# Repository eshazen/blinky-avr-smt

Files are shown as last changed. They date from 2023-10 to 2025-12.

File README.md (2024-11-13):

# blinky-avr-smt

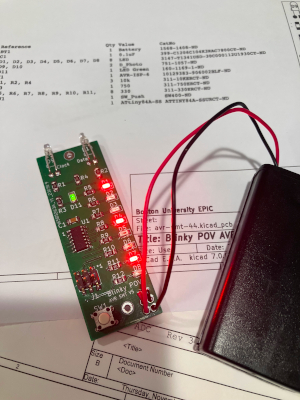
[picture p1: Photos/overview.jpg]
Overview Photo

Blinky

## Blinky POV soldering project

This is a soldering practice kit which displays a message in the air
on LEDs when waved back and forth.  

* Programming: https://ohm.bu.edu/~hazen/BlinkyPovAVR/prog/test_prog.html

## Revisions

Revision 5.1 PCB (fall 2023).  See [PCB Documentation](Hardware/avr-smt-44).

* Improve thermal relief on GND/VCC pads
* Change SMT programming connector to thru-hole
* Add pre-programmed message "EPIC"
* Improve error-checking and display on download code
  (blink all LEDs on checksum error)

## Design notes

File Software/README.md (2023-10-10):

This folder contains software in C to run on the Blinky POV AVR Rev 4 hardware.
The thru-hole version fabricated last in 2014 and a new SMT version fabricated
in 2023 are interchangeable from a software standpoint.

### "test1" is a simple LED test

### "Firmware_V4" is the main blinky firmware.

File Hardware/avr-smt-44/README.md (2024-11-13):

# avr-smt-44

KiCAD design for an SMT version based on ATTiny44/84.
Should be pin/firmware compatible with BlinkyPovAVR4.

## Documentation

* [avr-smt-44.pdf](avr-smt-44.pdf) -- Electrical Schematic
* [avr-smt-44.step](avr-smt-44.step) -- 3D model of assembled board
* [avr-smt-44-Edge_Cuts.pdf](avr-smt-44-Edge_Cuts.pdf) -- Assembly/mechanical drawing
* [avr-smt-44-Edge_Cuts.dxf](avr-smt-44-Edge_Cuts.dxf) -- Assembly/mechanical drawing

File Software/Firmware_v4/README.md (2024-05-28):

# Firmware_v4

This is a C program designed to run on an ATTiny44/84 micro.
It displays a message of up to 127 characters in a 5x8 bitmap on a
column of 8 LEDs.  The character set includes [0-9 A-Z .!&?,].

A new message can be downloaded by pointing the board with two light
sensors at a Javascript applet which converts the text message to a
simplified Intel Hex format and transmits it as a binary code.  Two
squares on the monitor represent "clock" (strobe) and "data".

## Build instructions

On Ubuntu Linux, install the packages `avr-libc`, `gcc-avr` and `avrdude`.
You also need gnu make (suggest to install `build-essential`).

(It is certainly possible to build and download the code on
other OS but I don't have documentation for that.  Google is your friend!)

On Linux:  edit `Makefile` to set `DUDEPORT` appropriately for your programmer.
Two common options are:
* `-c avrispv2 -P usb` for the official ISP V2 or clone
* `-c usbtiny -P usb` for a "USB Tiny" or clone
* `-c avrisp -P /dev/ttyACM0 -b 19200` for Arduino-as-ISP (untested!)

Type `make` to build:

    $ make
    avr-gcc -c -std=c99 -g -Os -mmcu=attiny84 -DF_CPU=1000000 main.c -o main.o
    avr-gcc -Wl,-Map=main.map,--cref -mmcu=attiny84 main.o -o main.elf
    avr-objcopy -j .text -j .data -O ihex main.elf main.hex
    avr-objdump -h -S main.elf > main.lst
    avr-size --common -d main.elf
       text    data     bss     dec     hex filename
       2708      10     171    2889     b49 main.elf

Connect the programming adapter to the 6 pin connector `J1`.
(You may have to install this yourself).

Type `make flash` to program the flash.

## Bugs

Messages longer than 15 characters currently aren't handled correctly
and corrupt the EEPROM.  

For now:  modify the programming code to not allow this

## Details

Each clock pulse causes two data bits to be sampled, the first on the
rising edge and the second on the falling edge.  The most-significant
bit of data is sent first, with 4 clock pulses per byte.

The hex record format is as follows:

`NNHHLLTTDD....CC`

Where:

`NN` is the record length.  0 is ignored, 01-0F are valid

`HH` and `LL` represent the starting address in EEPROM.

`TT` is the record type.  00 represents end-of-message

`CC` is an 8 bit checksum on the data

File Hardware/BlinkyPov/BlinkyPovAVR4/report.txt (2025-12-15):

Info: Backing up file '/home/hazen/work/blinky-avr-smt/Hardware/BlinkyPov/BlinkyPovAVR4/sym-lib-table' to '/home/hazen/work/blinky-avr-smt/Hardware/BlinkyPov/BlinkyPovAVR4/rescue-backup/sym-lib-table-2025-12-15-13-13-25'.
Info: Backing up file '/home/hazen/work/blinky-avr-smt/Hardware/BlinkyPov/BlinkyPovAVR4/tute1.sch' to '/home/hazen/work/blinky-avr-smt/Hardware/BlinkyPov/BlinkyPovAVR4/rescue-backup/tute1-2025-12-15-13-13-25.sch'.
Info: Backing up file '/home/hazen/work/blinky-avr-smt/Hardware/BlinkyPov/BlinkyPovAVR4/tute1.kicad_pro' to '/home/hazen/work/blinky-avr-smt/Hardware/BlinkyPov/BlinkyPovAVR4/rescue-backup/tute1-2025-12-15-13-13-25.kicad_pro'.
Info: Backing up file '/home/hazen/work/blinky-avr-smt/Hardware/BlinkyPov/BlinkyPovAVR4/tute1-cache.lib' to '/home/hazen/work/blinky-avr-smt/Hardware/BlinkyPov/BlinkyPovAVR4/rescue-backup/tute1-cache-2025-12-15-13-13-25.lib'.
Info: Backing up file '/home/hazen/work/blinky-avr-smt/Hardware/BlinkyPov/BlinkyPovAVR4/tute1.cache.lib' to '/home/hazen/work/blinky-avr-smt/Hardware/BlinkyPov/BlinkyPovAVR4/rescue-backup/tute1.cache-2025-12-15-13-13-25.lib'.
Info: Backing up file '/home/hazen/work/blinky-avr-smt/Hardware/BlinkyPov/BlinkyPovAVR4/tute1-rescue.lib' to '/home/hazen/work/blinky-avr-smt/Hardware/BlinkyPov/BlinkyPovAVR4/rescue-backup/tute1-rescue-2025-12-15-13-13-25.lib'.
Info: Backing up file '/home/hazen/work/blinky-avr-smt/Hardware/BlinkyPov/BlinkyPovAVR4/tute1-rescue.dcm' to '/home/hazen/work/blinky-avr-smt/Hardware/BlinkyPov/BlinkyPovAVR4/rescue-backup/tute1-rescue-2025-12-15-13-13-25.dcm'.
Info: Adding library 'tute1-rescue', file '${KIPRJMOD}/tute1-rescue.lib' to project symbol library table.
Info: Created project symbol library table.

Symbol CONN_1 mapped to symbol library 'tute1-rescue'.
Symbol CONN_1 mapped to symbol library 'tute1-rescue'.
Symbol CONN_1 mapped to symbol library 'tute1-rescue'.
Symbol LED mapped to symbol library 'tute1-rescue'.
Symbol LED mapped to symbol library 'tute1-rescue'.
Symbol LED mapped to symbol library 'tute1-rescue'.
Symbol LED mapped to symbol library 'tute1-rescue'.
Symbol LED mapped to symbol library 'tute1-rescue'.
Symbol LED mapped to symbol library 'tute1-rescue'.
Symbol LED mapped to symbol library 'tute1-rescue'.
Symbol LED mapped to symbol library 'tute1-rescue'.
Symbol R mapped to symbol library 'tute1-rescue'.
Symbol LED mapped to symbol library 'tute1-rescue'.
Symbol LED mapped to symbol library 'tute1-rescue'.
Symbol GND mapped to symbol library 'tute1-rescue'.
Symbol R mapped to symbol library 'tute1-rescue'.
Symbol R mapped to symbol library 'tute1-rescue'.
Symbol VCC mapped to symbol library 'tute1-rescue'.
Symbol GND mapped to symbol library 'tute1-rescue'.
Symbol ATTINY44A-P mapped to symbol library 'tute1-rescue'.
Symbol CONN_1 mapped to symbol library 'tute1-rescue'.
Symbol VCC mapped to symbol library 'tute1-rescue'.
Symbol CONN_1 mapped to symbol library 'tute1-rescue'.
Symbol GND mapped to symbol library 'tute1-rescue'.
Symbol CONN_1 mapped to symbol library 'tute1-rescue'.
Symbol C mapped to symbol library 'tute1-rescue'.
Symbol BATTERY mapped to symbol library 'tute1-rescue'.
Symbol GND mapped to symbol library 'tute1-rescue'.
Symbol SW_PUSH mapped to symbol library 'tute1-rescue'.
Info: Symbol library table mapping complete!
Info: Created project symbol library table.

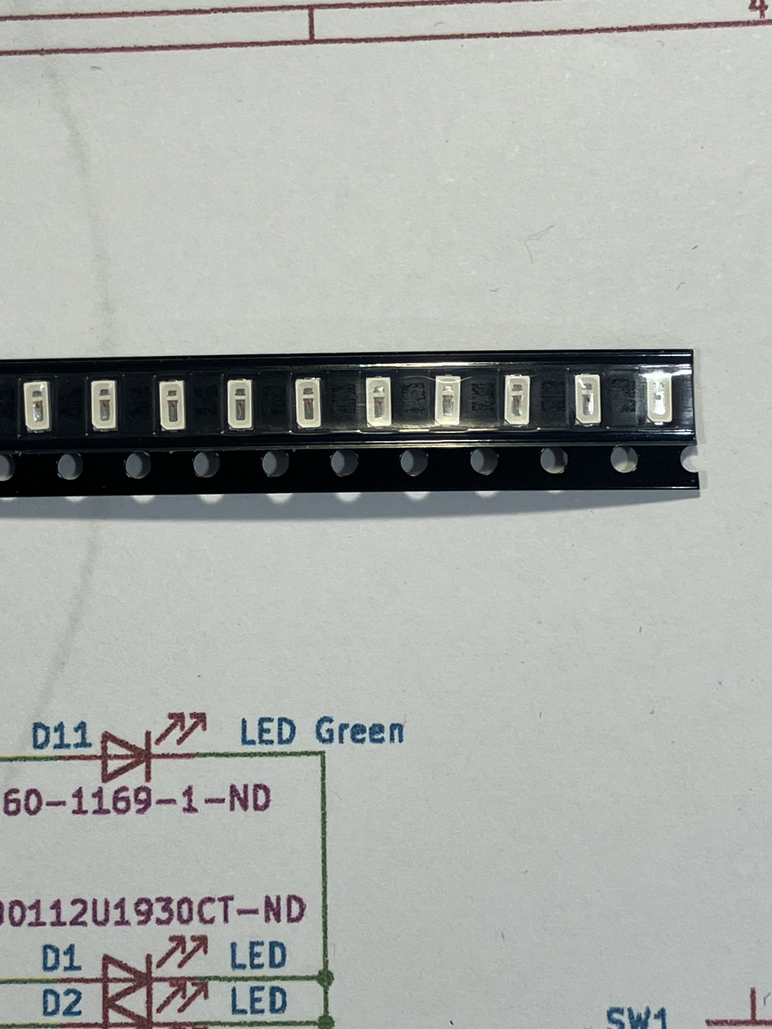
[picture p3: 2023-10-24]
Photos/2023-10-17 13.31.52.jpg

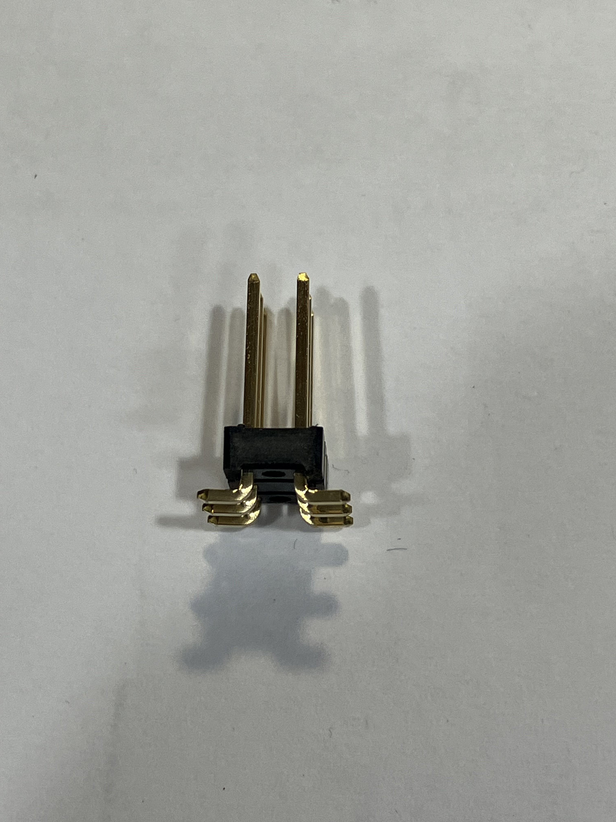
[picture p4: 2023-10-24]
Photos/2023-10-17 13.57.07.jpg

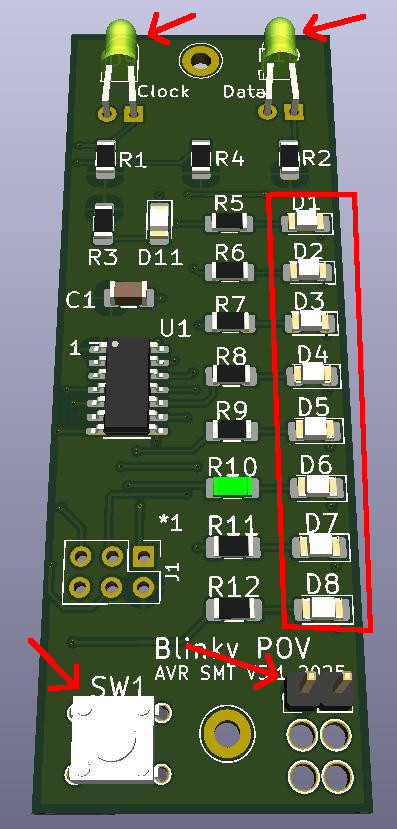
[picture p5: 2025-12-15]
Case2/blinky_3D_front_callouts.jpg

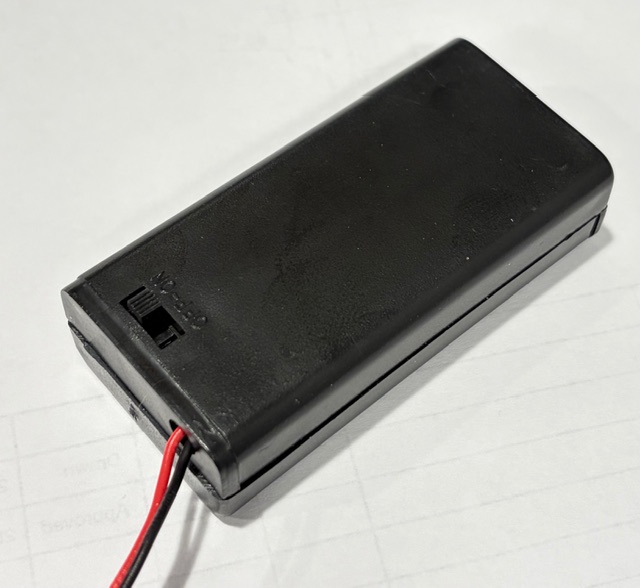
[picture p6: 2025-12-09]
Case2/bat_holder.jpg

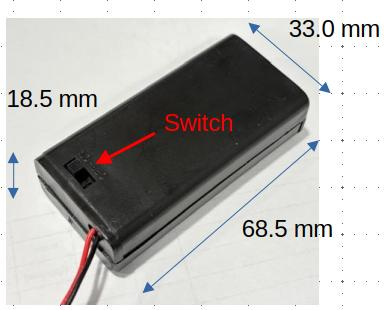
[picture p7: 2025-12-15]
Case2/battery_holder_dims.png

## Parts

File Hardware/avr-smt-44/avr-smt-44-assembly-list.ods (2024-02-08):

# | Reference | Qty | Value | CatNo
1 | BT1 | 1 | Battery | 1568-1408-ND
2 | C1 | 1 | 0.1uF | 399-C1206C104K3RAC7800CT-ND
3 | D1, D2, D3, D4, D5, D6, D7, D8 | 8 | LED | 3147-T1341USD-30C000112U1930CT-ND
4 | D9, D10 | 2 | D_Photo | 751-1057-ND
5 | D11 | 1 | LED Green | 160-1169-1-ND
7 | R1, R2, R4 | 3 | 10k | 311-10KERCT-ND
8 | R3 | 1 | 750 | 311-750ERCT-ND
9 | R5, R6, R7, R8, R9, R10, R11, R12 | 8 | 330 | 311-330ERCT-ND
10 | SW1 | 1 | SW_Push | SW400-ND
11 | U1 | 1 | ATtiny84A-SS | ATTINY84A-SSURCT-ND

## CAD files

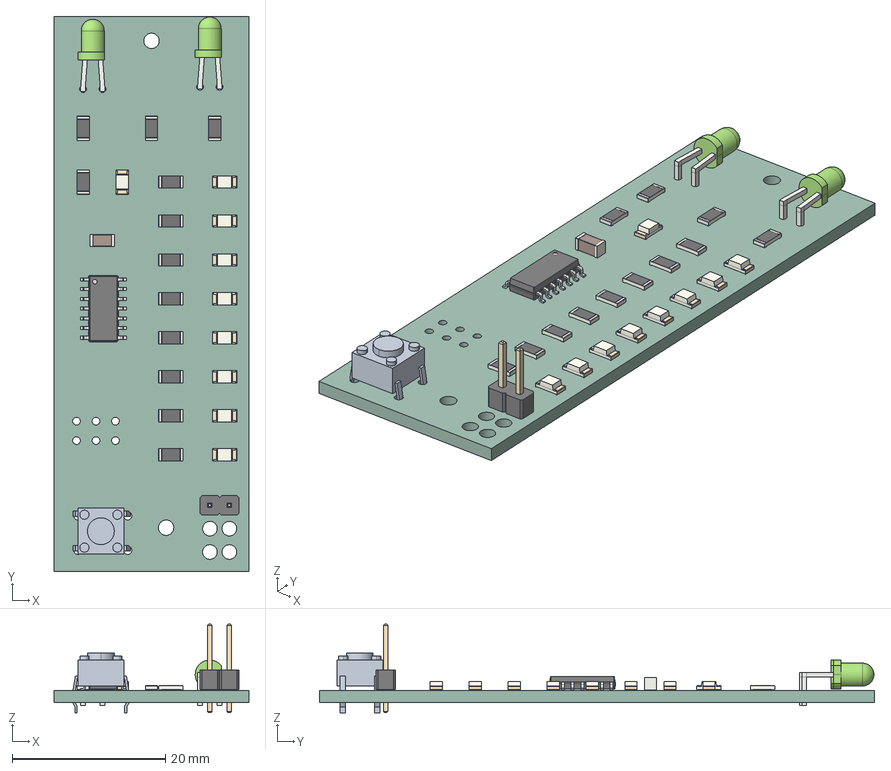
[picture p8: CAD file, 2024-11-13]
Hardware/avr-smt-44/avr-smt-44.step
25.4 x 72.4 x 11.6 mm
C_1206_3216Metric
R_1206_3216Metric x 12
B3F_1000
LED_1206_3216Metric x 9
PinHeader_1x02_P254mm_Vertical
SOIC_14_39x87mm_P127mm
LED_D3.0mm_Horizontal_O3.81mm_Z2.0mm x 2
avr-smt-44_PCB

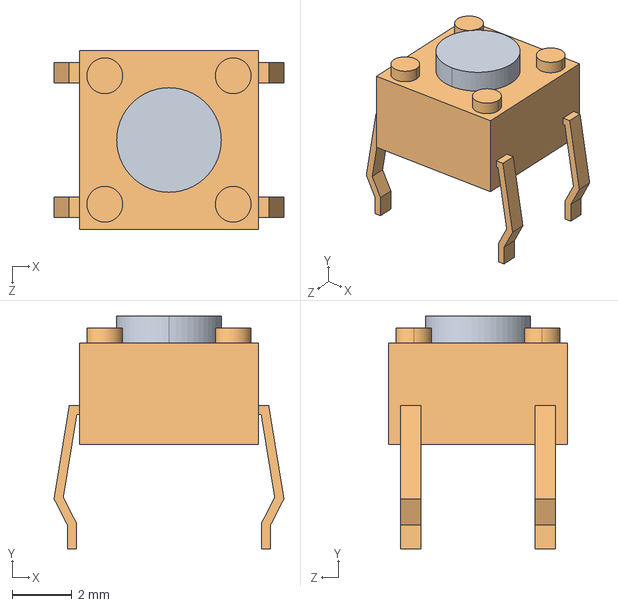
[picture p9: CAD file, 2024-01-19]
Hardware/avr-smt-44/models/B3F-1000.step
7.70 x 7.80 x 6.00 mm
B3F_1000_BUTTON
B3F_1000_BASE

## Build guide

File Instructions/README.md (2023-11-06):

# Instructions for Blinky project

* [Slides](slides.pdf)
* [Kit Page](Kit_Page.pdf) - laminated sheet for parts
* [Assembly Drawing](avr-smt-44-assembly-dwg.pdf)
* [Assembly Notes](Orientation.pdf)
* [Photo](finished.jpg) of completed board

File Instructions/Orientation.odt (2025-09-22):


Blinky POV
Kit

# Assembly Notes

Rev 7/7/25

The assembly drawing is your main reference for placing components on the board. The bill of materials (parts list) includes a “Reference” column which matches the labels on the board (“R1” etc).

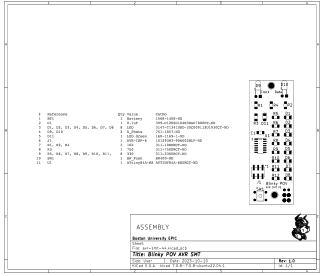
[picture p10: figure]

Docs page:
https://github.com/eshazen/blinky-avr-smt

Resistors and capacitors (R and C) are reversible and can be soldered either way around.

The rest of the parts are not reversible and must be installed the right way around.

Microcontroller (U1)
LEDs (D1-D8 and D11)
Light sensors (D9 and D10)
Battery holder wires

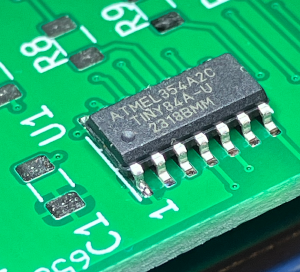
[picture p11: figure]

U1 Orientation

Pin 1 is marked by a dimple in the top of the chip. This should go next to the number “1” on the board.

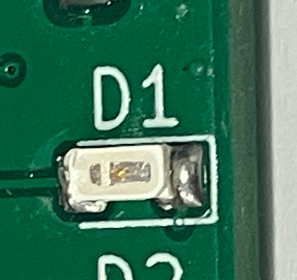
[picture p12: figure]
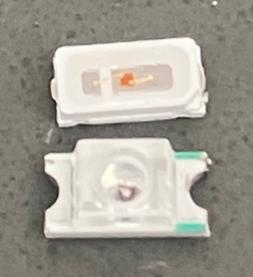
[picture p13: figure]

The LEDs D1-D8 should be mounted as shown.
There are two types of LED… one with a small white bar which goes to the left, the other with green dots which go to the right.

They should be mounted with the white surface with a transparent window facing up.

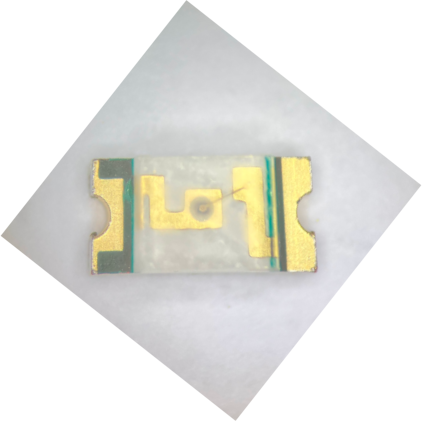
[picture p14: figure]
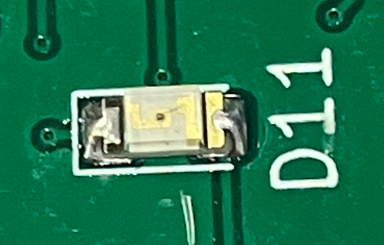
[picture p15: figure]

LED D11 orientation.
You have to look closely
for this one.

LEDs are the most common
type of component to install
incorrectly!

The light sensors (D9, D10) have leads of different lengths.
Bend and install as shown.
Long lead in left hole

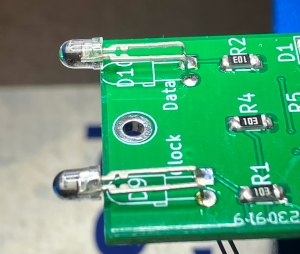
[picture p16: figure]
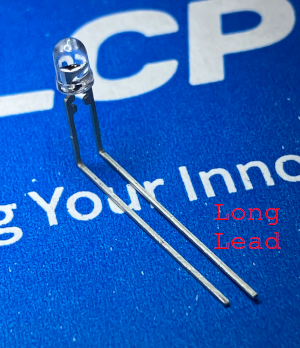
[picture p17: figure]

Trim the extra leads off on the back

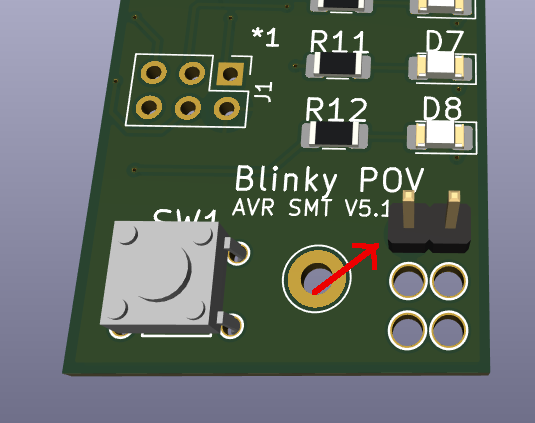
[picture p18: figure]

J1 is not installed

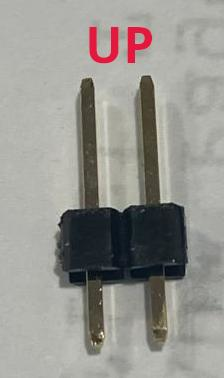
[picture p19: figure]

Install a two-pin header as shown for the battery. The longer pins point UP.

Install the switch SW1 as shown.

Battery connects with Red lead to left

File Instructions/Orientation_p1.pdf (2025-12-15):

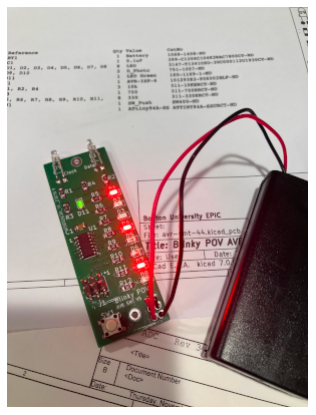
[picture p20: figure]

# Blinky POV Kit

## Assembly Notes

Rev 7/7/25

The assembly drawing is your main reference for placing components on the board. The bill of materials (parts list) includes a “Reference” column which matches the labels on the board
(“R1” etc).
Docs page:


### https://github.com/eshazen/blinky-avr-smt

Resistors and capacitors (R and C) are reversible and can be soldered either way around. The rest of the parts are not reversible and must be installed the right way around. Microcontroller (U1)
LEDs (D1-D8 and D11)
Light sensors (D9 and D10)
Battery holder wires
U1 Orientation
Pin 1 is marked by a dimple in the top of the chip. This should go next to the number “1” on the board.

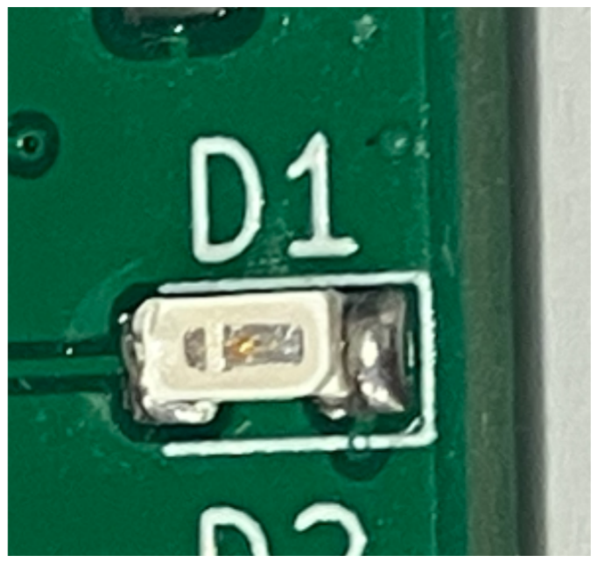
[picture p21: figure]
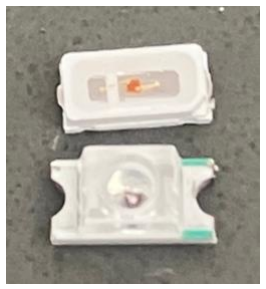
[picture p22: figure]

The LEDs D1-D8 should be mounted as shown. There are two types of LED… one with a small white bar which goes to the left, the other with green dots which go to the right.
They should be mounted with the white surface with a transparent window facing up.

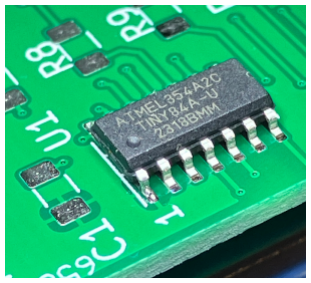
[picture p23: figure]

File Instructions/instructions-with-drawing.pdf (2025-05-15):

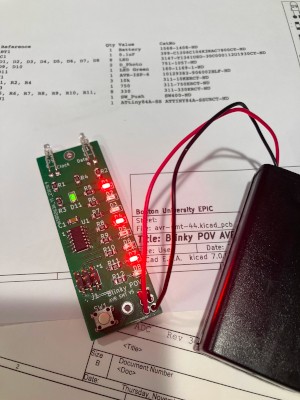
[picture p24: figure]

### Blinky POV

### Kit

Assembly Notes

Rev 5/23/24

The assembly drawing is your main reference for placing components on the board. The bill of materials (parts list) includes a “Reference” column which matches the labels on the board
(“R1” etc).
Docs page:

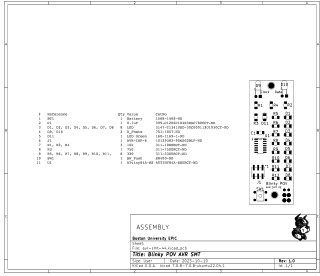
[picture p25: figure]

https://github.com/eshazen/blinky-avr-smt

Resistors and capacitors (R and C) are reversible and can be soldered either way around. The rest of the parts are not reversible and must be installed the right way around. Microcontroller (U1)
LEDs (D1-D8 and D11)
Light sensors (D9 and D10)
Battery holder wires
U1 Orientation
Pin 1 is marked by a dimple in the top of the chip. This should go next to the number “1” on the board.

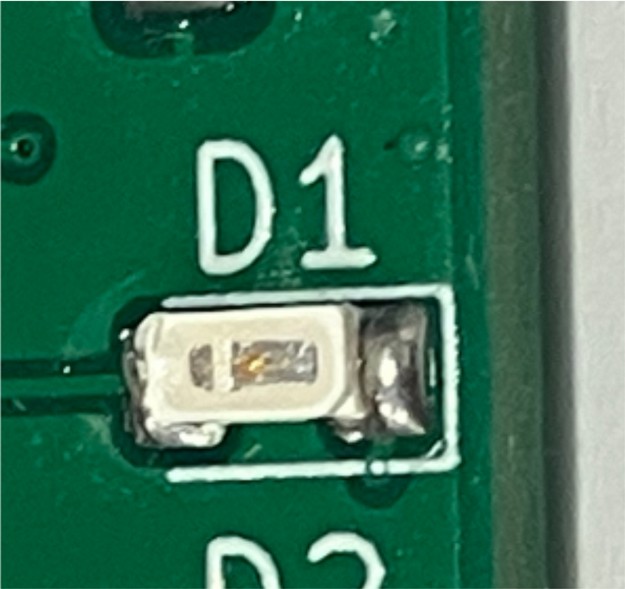
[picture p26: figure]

The LEDs D1-D8 should be mounted as shown, with the wider opening towards the board edge.
They should be mounted with the white surface with a transparent window facing up.

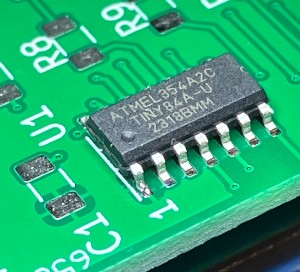
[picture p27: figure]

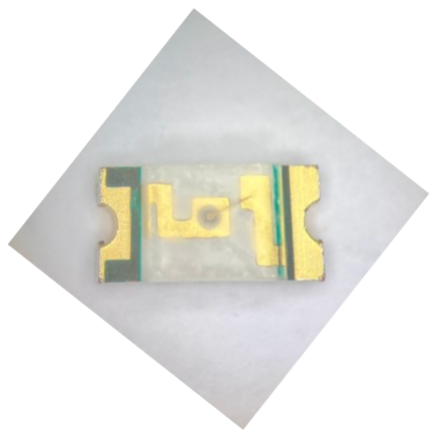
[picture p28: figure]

LED D11 orientation.
You have to look closely
for this one.

LEDs are the most common
type of component to install incorrectly!

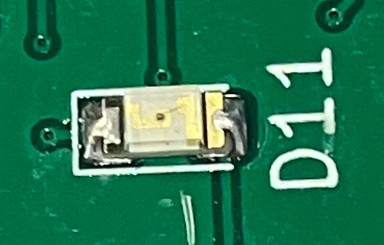
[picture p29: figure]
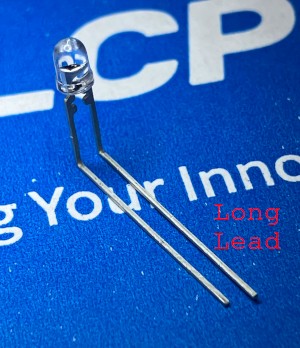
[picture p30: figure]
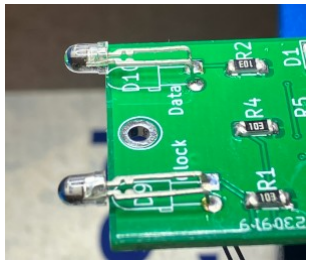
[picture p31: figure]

The light sensors (D9, D10) have leads of different lengths.
Bend and install as shown.
Long lead in left hole
Trim the extra leads off on the back

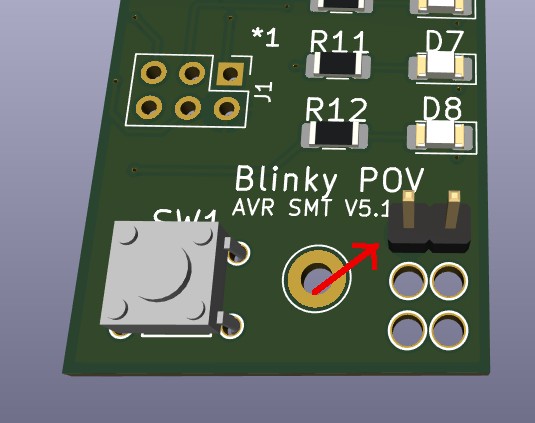
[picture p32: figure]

J1 is not installed
Install a two-pin header
as shown for the battery.
Install the switch SW1
as shown.
Battery connects with
Red lead to left

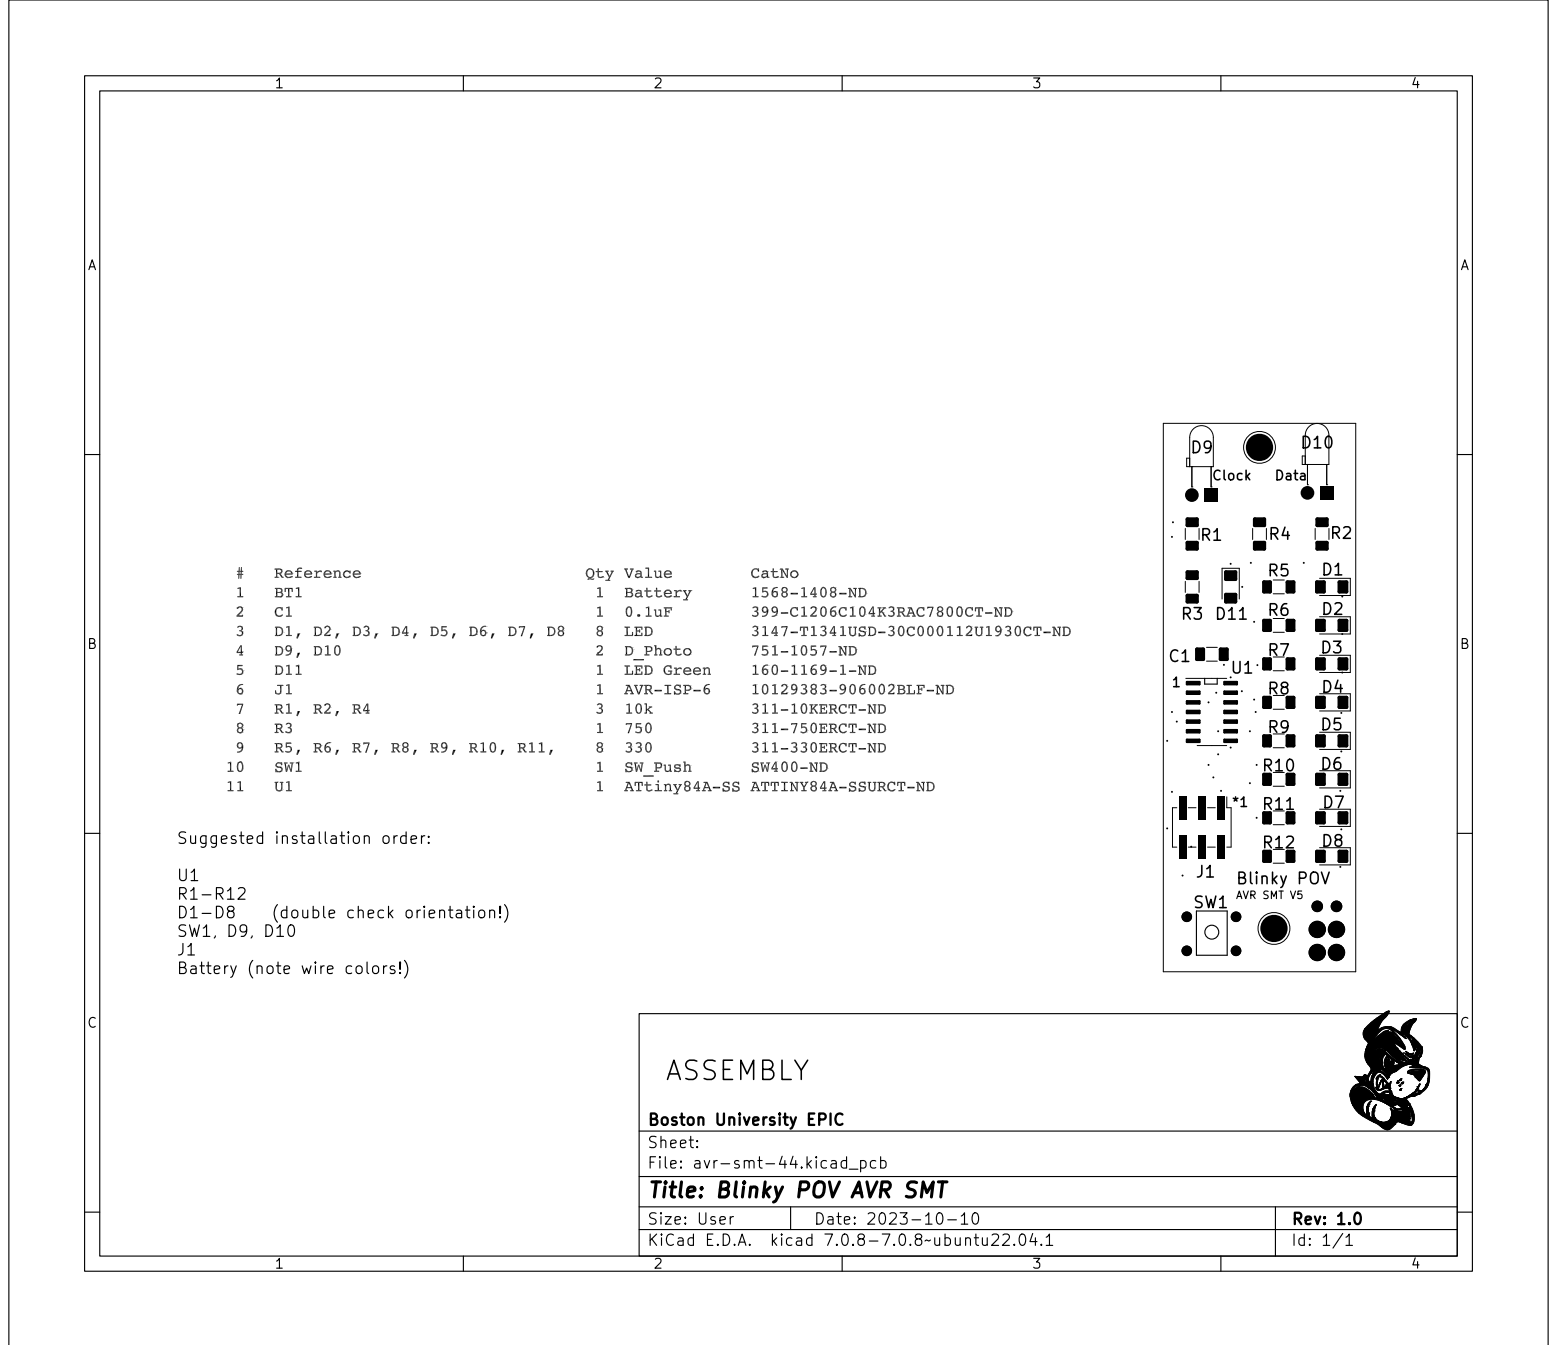
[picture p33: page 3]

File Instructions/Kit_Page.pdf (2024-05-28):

Blinky POV AVR SMT Kit V5.1

C1 – 0.1uF

D1-D8 – red LED

D9, D10 - photodiode

D11 – green LED

### 2 pin header

(battery, next to “V5.1”)

R1,R2,R4 – 10k resistor
R3 – 750 ohm resistor

R5..R12 – 330 ohm resistor

SW1 - pushbutton

U1 – ATTiny84 microcontroller

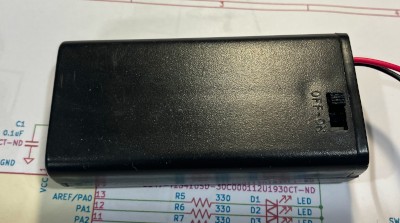
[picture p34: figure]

BT1 – Battery Case

Rev 5/23/24

Suggest to install in order...

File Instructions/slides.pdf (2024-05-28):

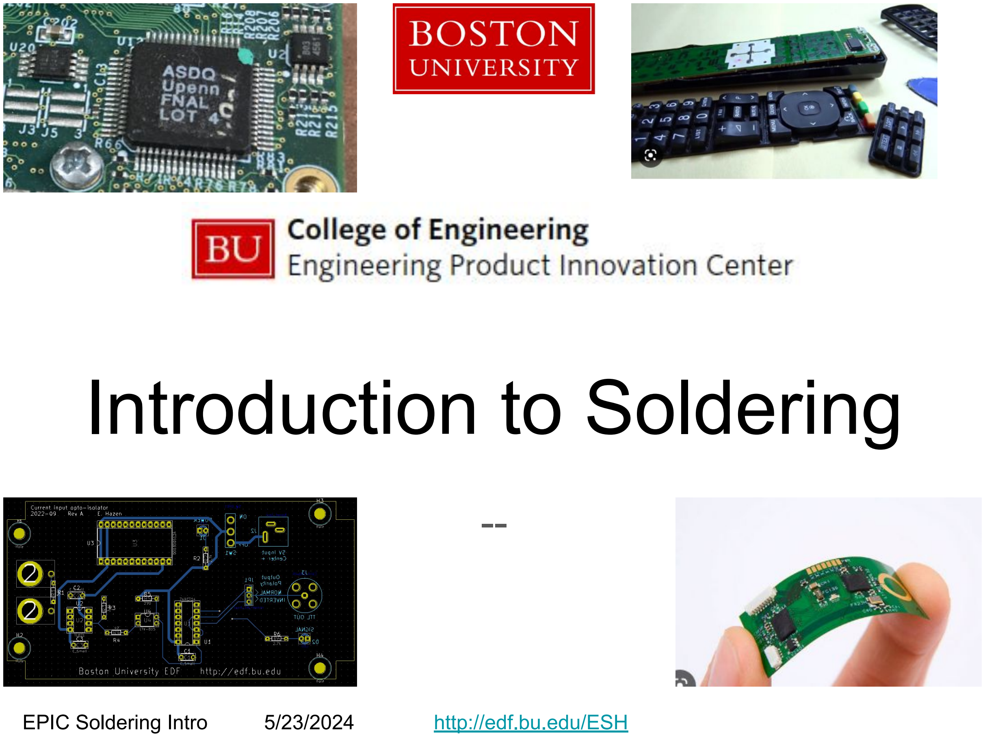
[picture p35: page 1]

EPIC Soldering Intro | 5/23/2024 | http://edf.bu.edu/ESH

# Introduction to Soldering

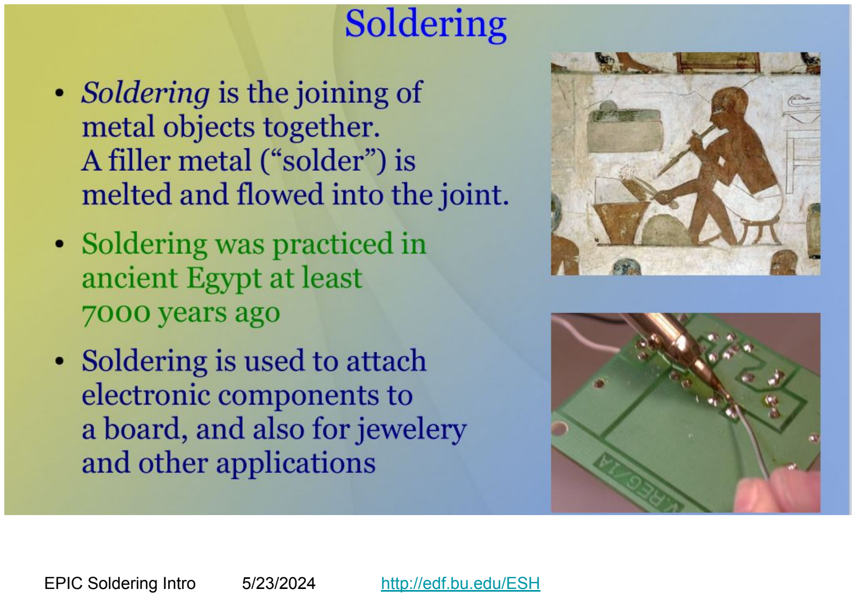
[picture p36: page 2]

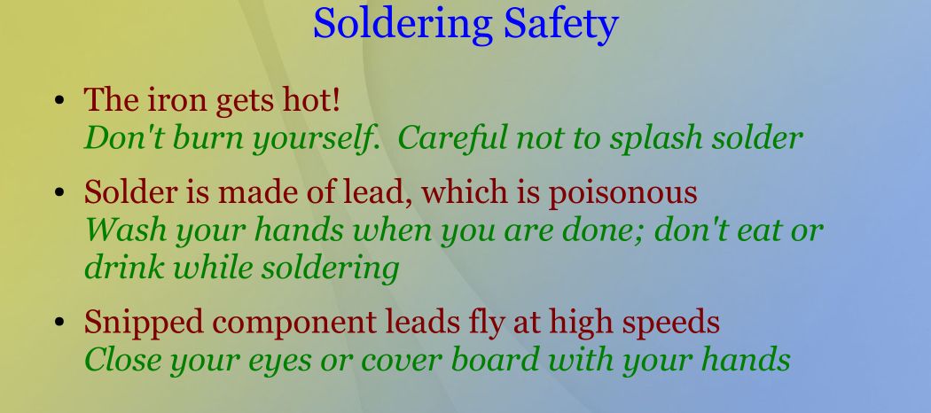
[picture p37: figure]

Thru-hole (THT) | vs | Surface Mount (SMT)

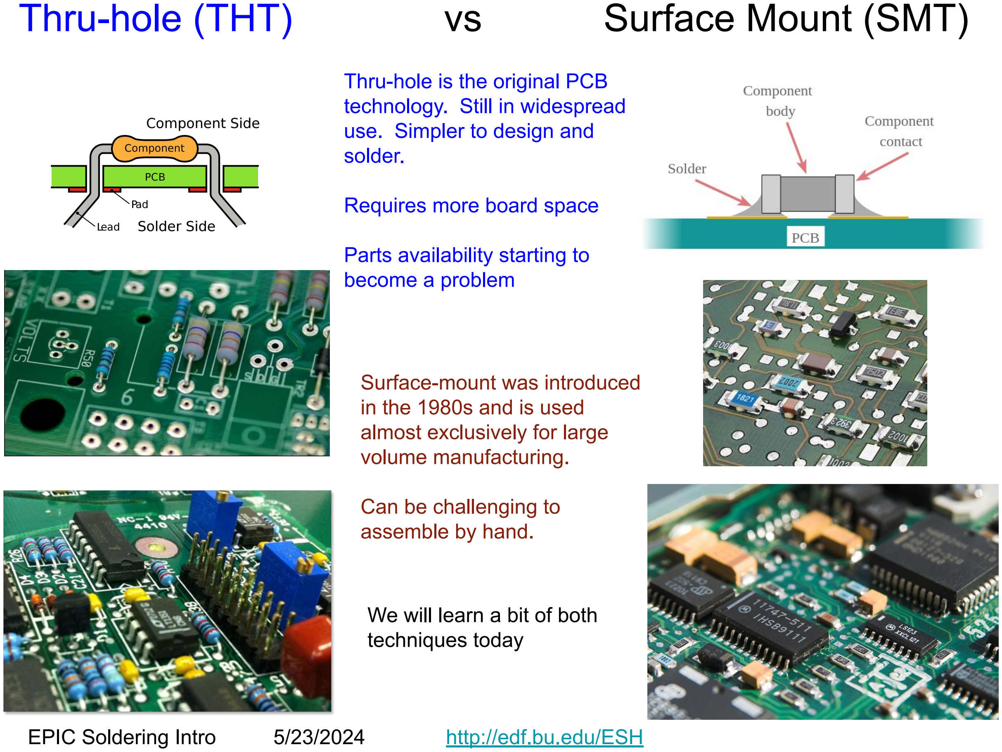
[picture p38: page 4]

Thru-hole is the original PCB technology. Still in widespread use. Simpler to design and solder.

Requires more board space

Parts availability starting to become a problem

Surface-mount was introduced in the 1980s and is used
almost exclusively for large volume manufacturing.

Can be challenging to
assemble by hand.

We will learn a bit of both techniques today

# Today’s Project!

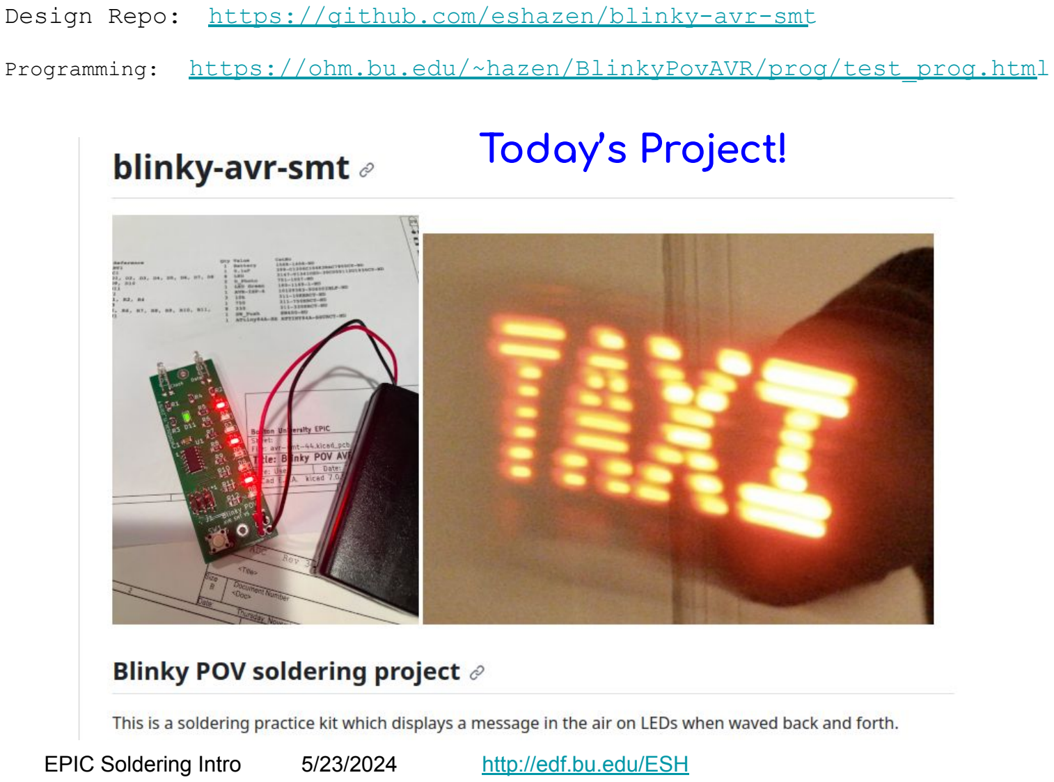
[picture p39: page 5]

Programming: | https://ohm.bu.edu/~hazen/BlinkyPovAVR/prog/test_prog.html
Design Repo: | https://github.com/eshazen/blinky-avr-smt

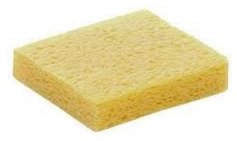
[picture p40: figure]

# Soldering - Tips and Tricks

## - Tin-Lead (PbSn) solder works best

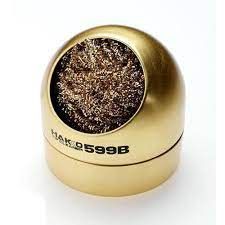
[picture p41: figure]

## - Get the sponge wet before starting - Set the iron temperature to ~ 750 F - Wipe the tip on the sponge and “tin” with new solder before each operation (if the tip gets dirty, clean on brass sponge) - If you aren’t using the iron, turn it off

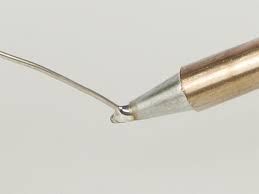
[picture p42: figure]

## The tip should look like this before you start soldering anything!

# Soldering two-terminal SMDs (resistors, capacitors)

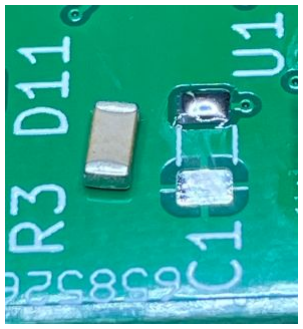
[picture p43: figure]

## - Apply solder to one pad (“tinning”) clean and tin soldering iron touch iron to pad count to 3 slowly feed in some solder keep iron on pad count to 3 slowly remove tip

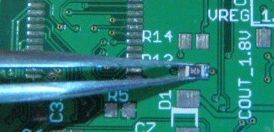
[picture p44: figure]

## - Heat solder until it melts Use tweezers to slide component into place

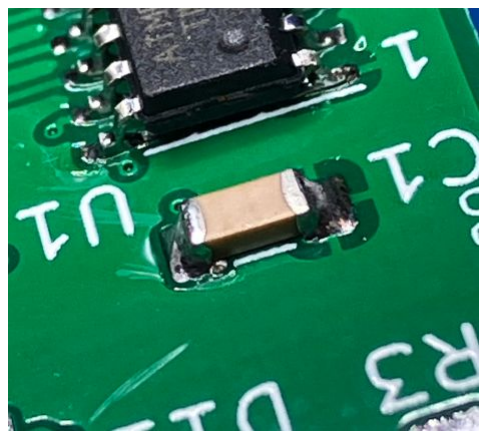
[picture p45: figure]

## - Heat the other end count to 3 apply some solder keep iron on joint count to 3

## SMD = Surface Mount Device

# Soldering Thru-Hole Devices

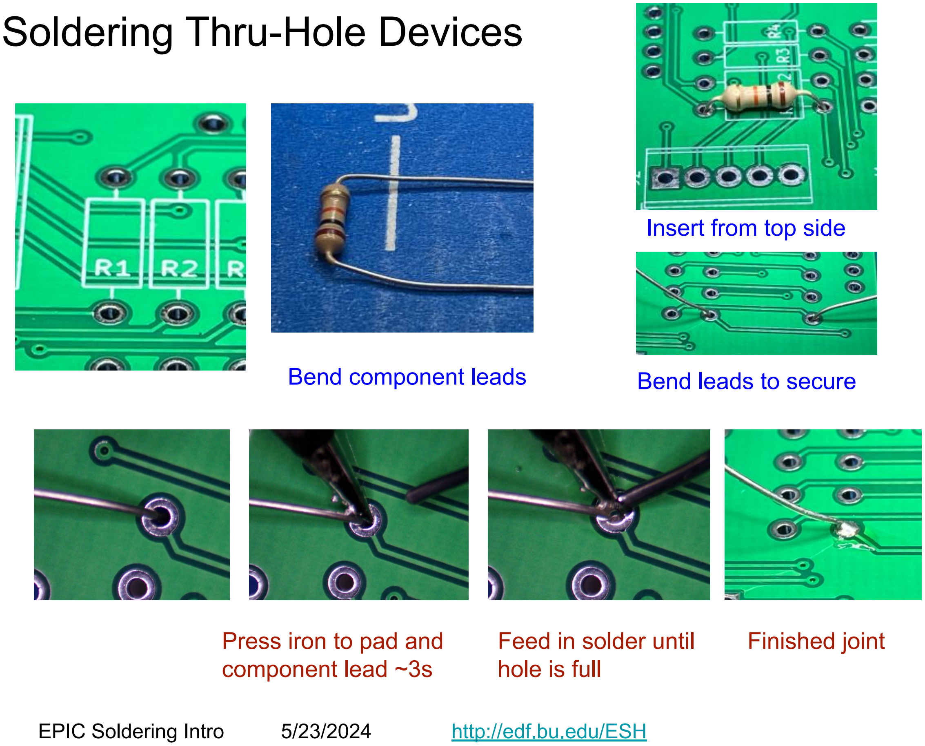
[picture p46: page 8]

Bend component leads

Insert from top side

Bend leads to secure

Press iron to pad and
component lead ~3s

Feed in solder until
hole is full

Finished joint

# Soldering - suggest to install in order on parts kit

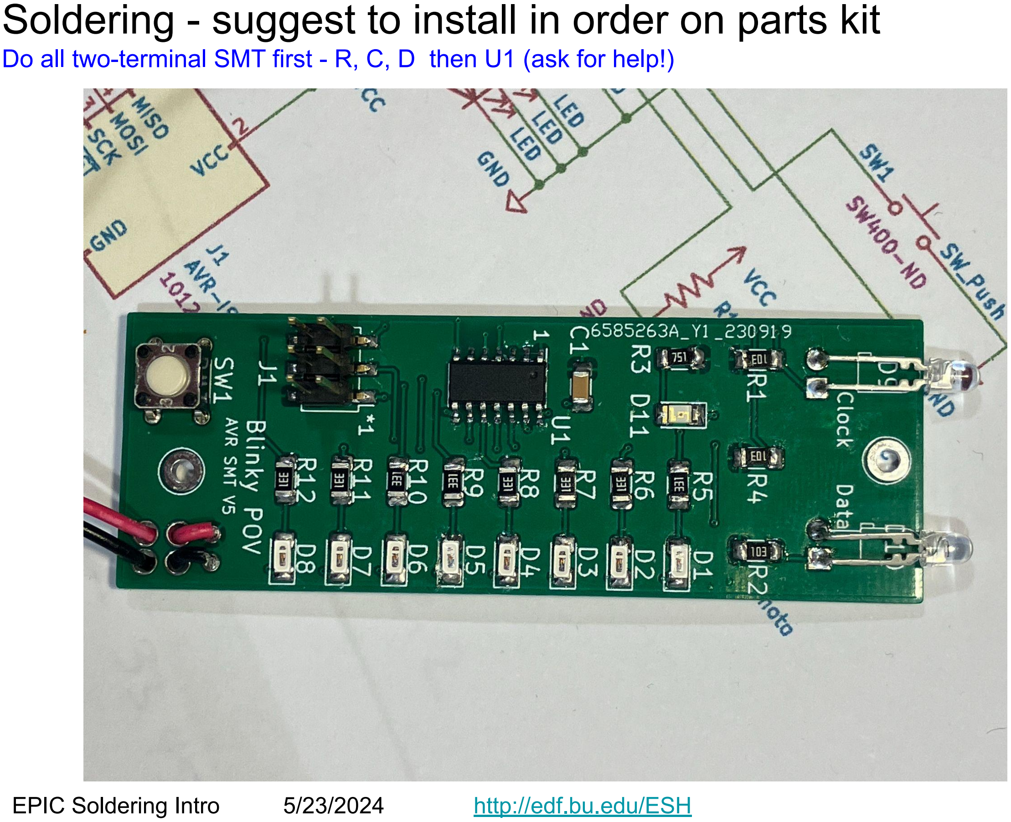
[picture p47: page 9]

Do all two-terminal SMT first - R, C, D then U1 (ask for help!)

# When you’re done…

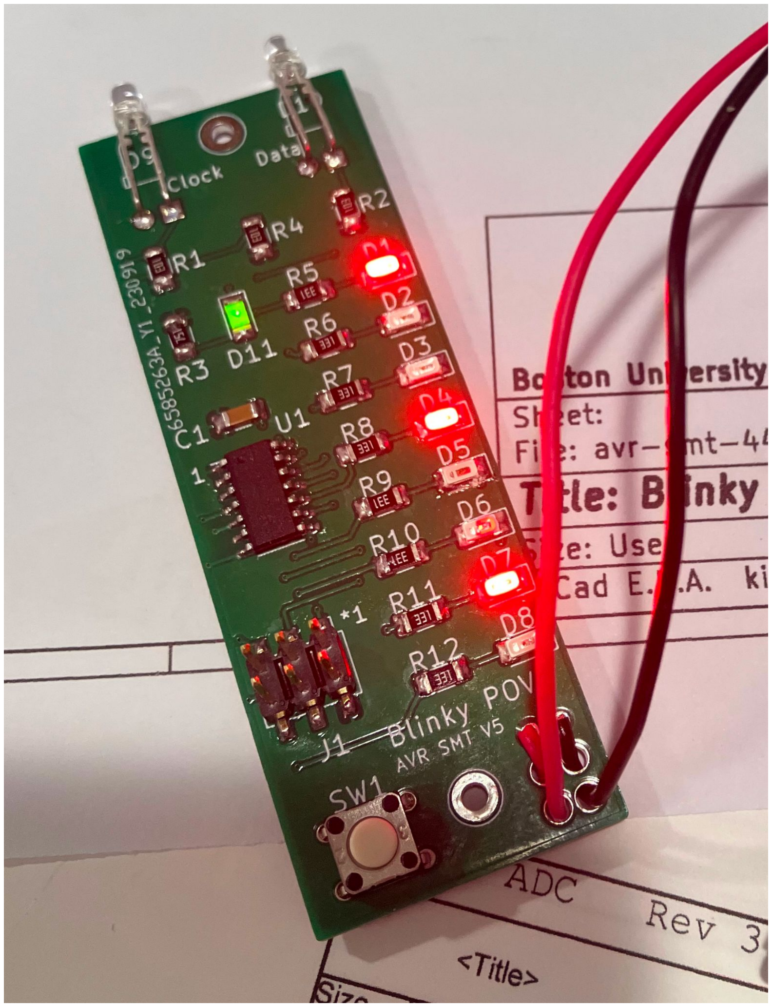
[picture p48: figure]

## After you finish soldering, get your work inspected

(This will prevent damage due to incorrectly installed parts)

## Connect battery with red wire to left

## Hold SW1 (button down) when powering up first

time to reset the message.

All LEDs should flash.

To program a new message into your board,

## visit this site:

https://ohm.bu.edu/~hazen/BlinkyPovAVR/prog/test_prog.html

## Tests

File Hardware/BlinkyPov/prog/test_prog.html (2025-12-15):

# Blinky POV Programming

Message:
Available characters: 0-9, A-Z, !, ?, &, \',\', and \'.\'.



Progress: Canceled

| | Delay (ms):

Data

Clock

Programming Instructions: Enter your message in the "Message" box.

- Hold board up to monitor as shown, with the LEDs up. The light sensors must point at the two squares marked "Clock" and "Data".
- Press the white button on the board. The top LED (D8) should come on and then go off.
- Click the "Go" button above. The squares will flash, and the top LED on your board should flash as the message is downloaded.

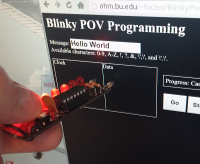
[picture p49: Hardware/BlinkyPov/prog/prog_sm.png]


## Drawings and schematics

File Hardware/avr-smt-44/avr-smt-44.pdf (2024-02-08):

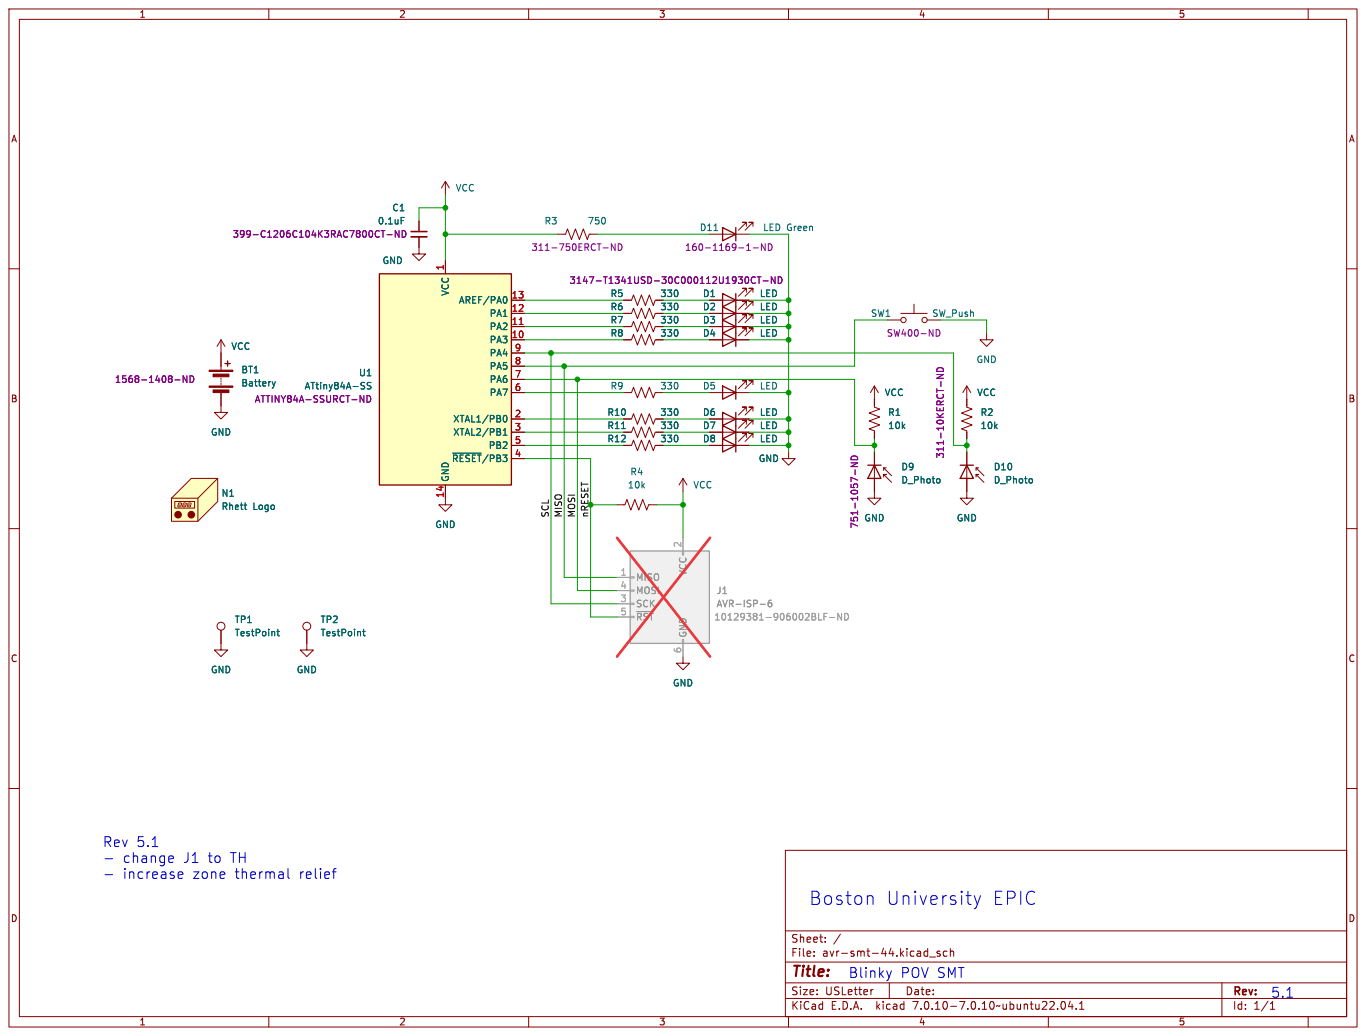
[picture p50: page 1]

1 PA3 10 PA2 11 PA1 12 AREF/PA0 13 GND 14 XTAL1/PB0 2 XTAL2/PB1 3 ~{RESET}/PB34 PB2 5 PA7 6 PA6 7 PA5 8 PA4 9 U1 ATtiny84A-SS

2 SCK 3 MOSI 4 ~{RST} 5 GND

Rev 5.1
- change J1 to TH
- increase zone thermal relief

Id: 1/1 Title: File: avr-smt-44.kicad_sch Sheet: /

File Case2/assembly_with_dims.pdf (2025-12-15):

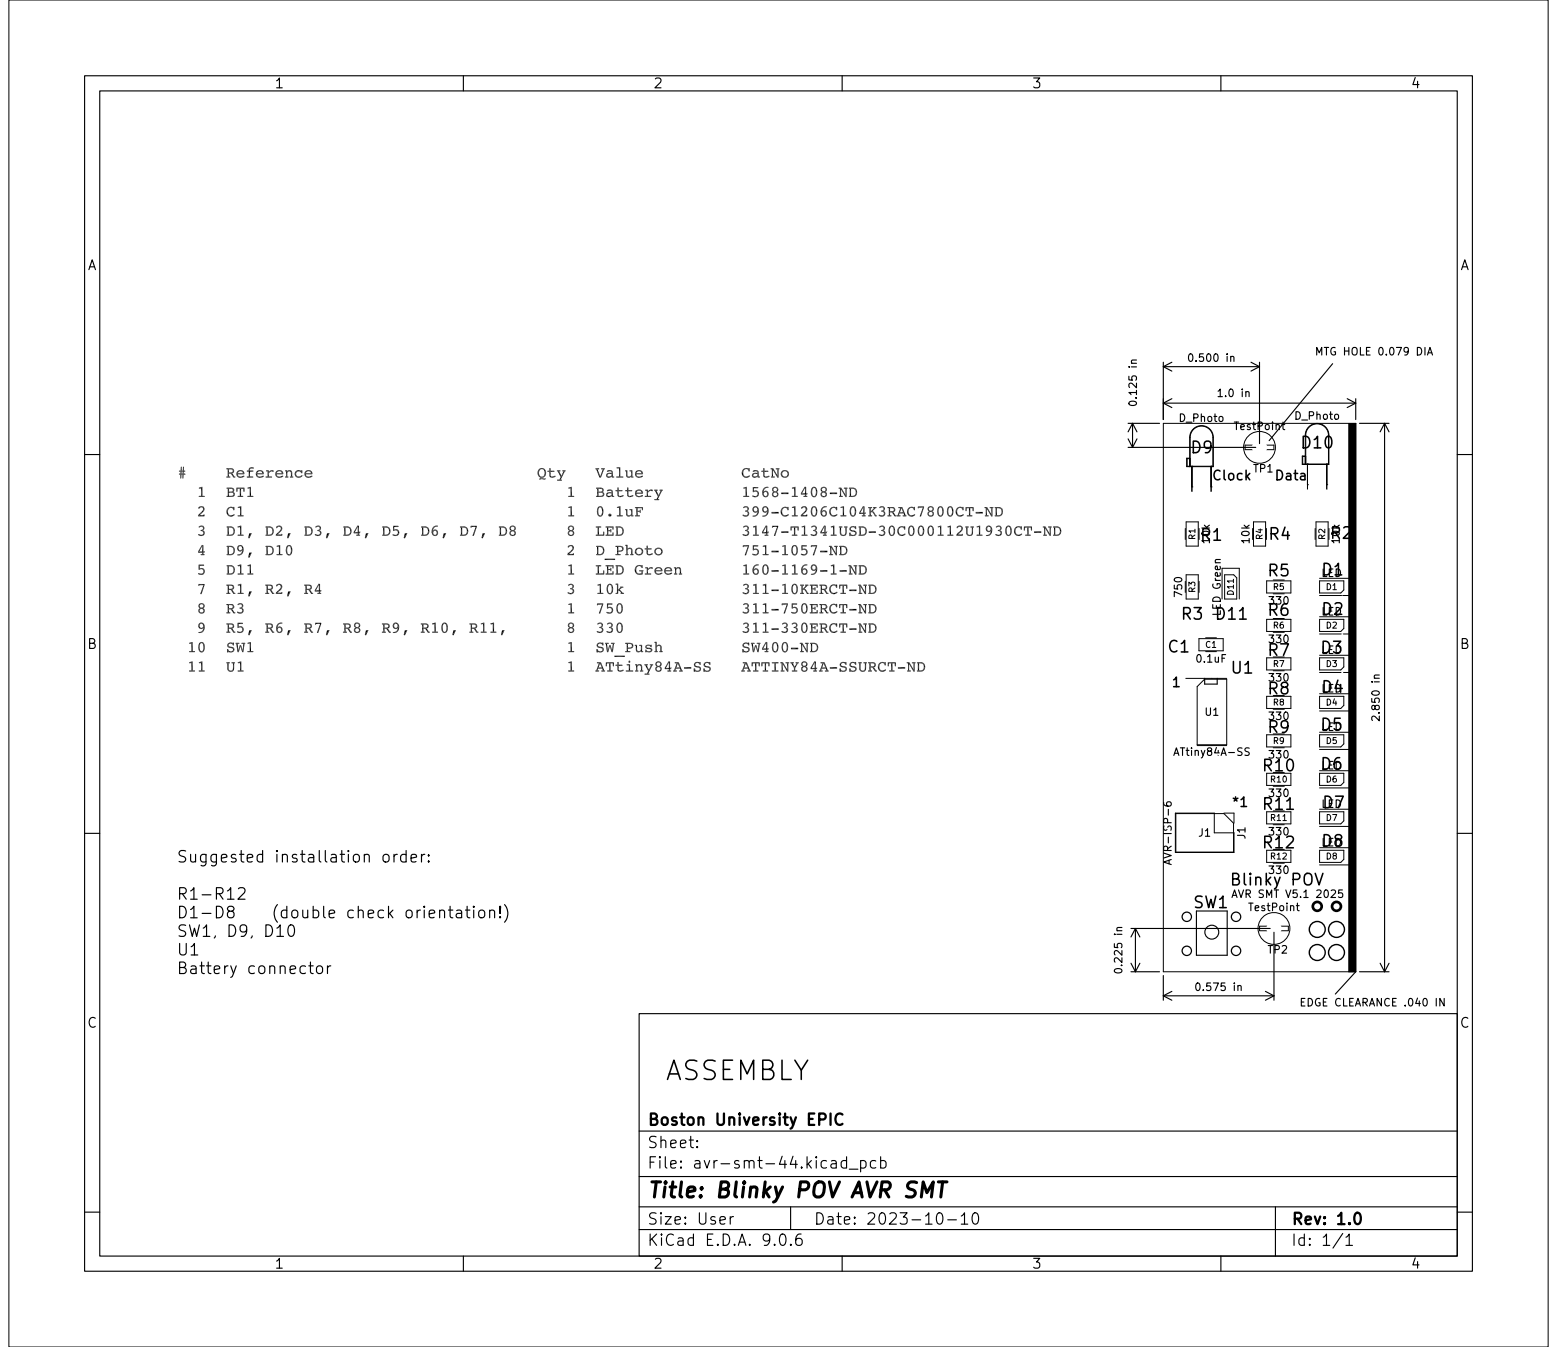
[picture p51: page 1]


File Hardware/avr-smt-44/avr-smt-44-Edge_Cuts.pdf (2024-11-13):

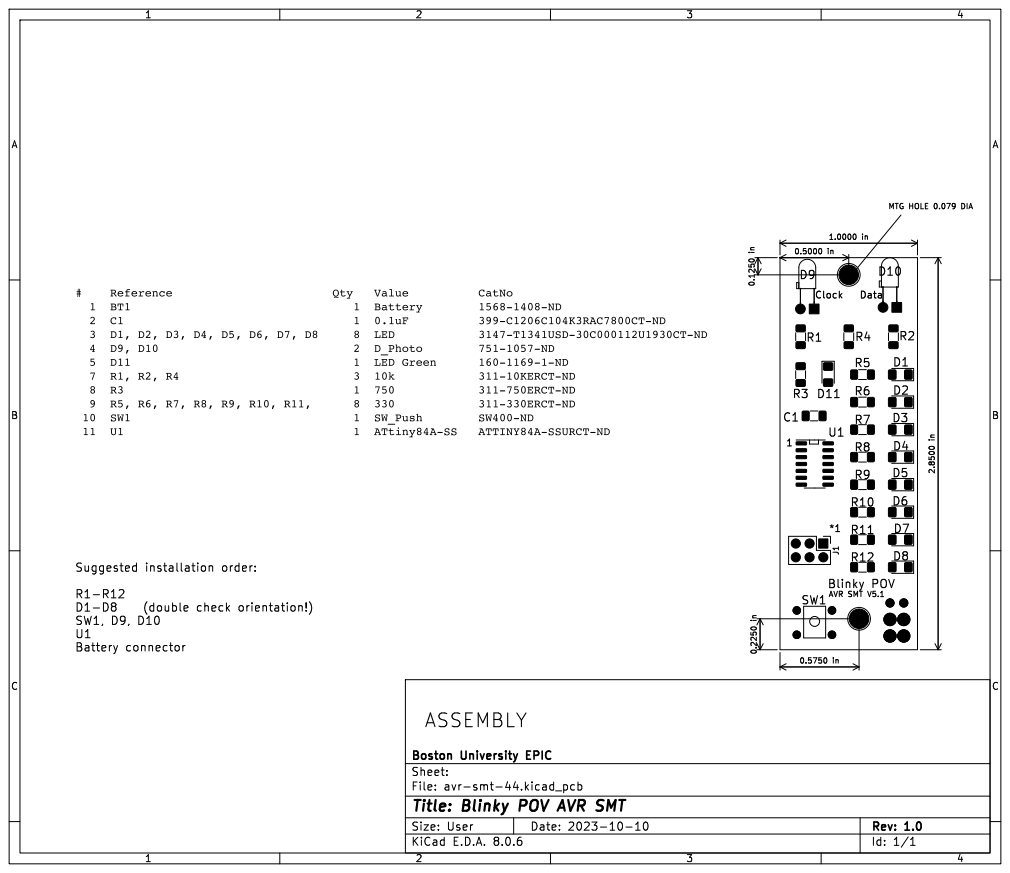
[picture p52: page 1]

Id: 1/1 Title: Blinky POV AVR SMT

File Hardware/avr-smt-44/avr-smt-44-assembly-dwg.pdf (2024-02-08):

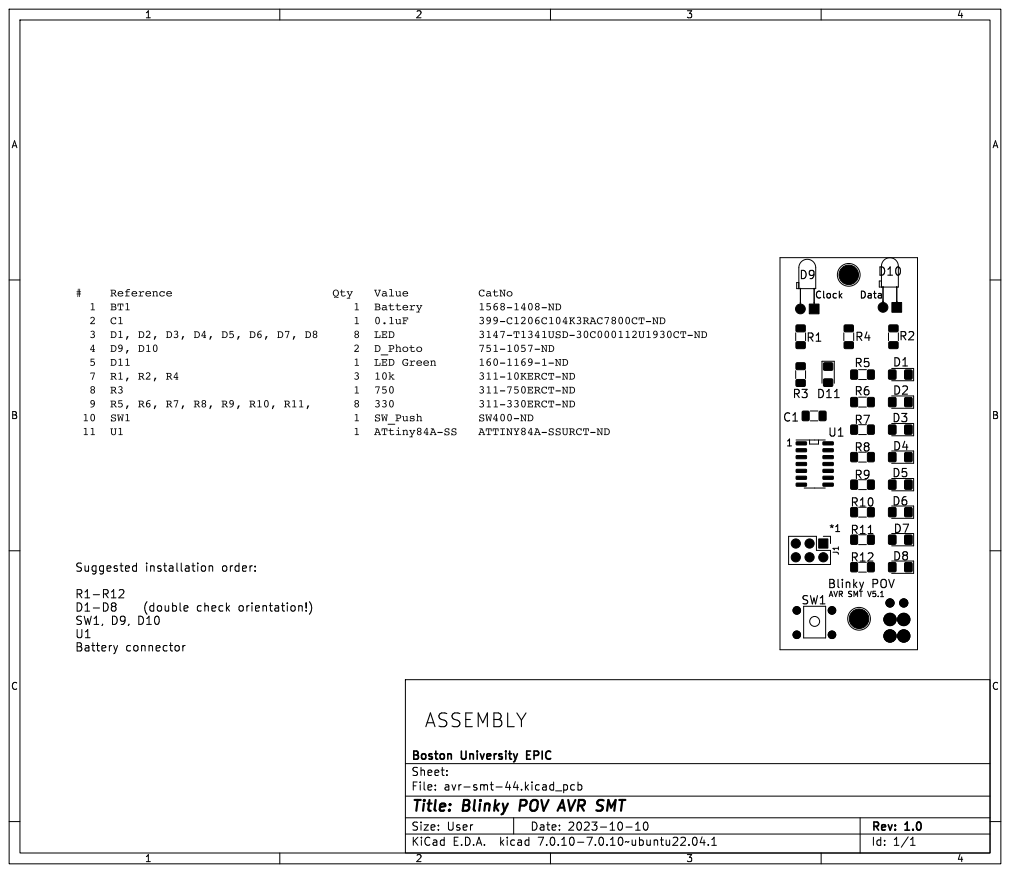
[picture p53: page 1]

Id: 1/1 Title: Blinky POV AVR SMT

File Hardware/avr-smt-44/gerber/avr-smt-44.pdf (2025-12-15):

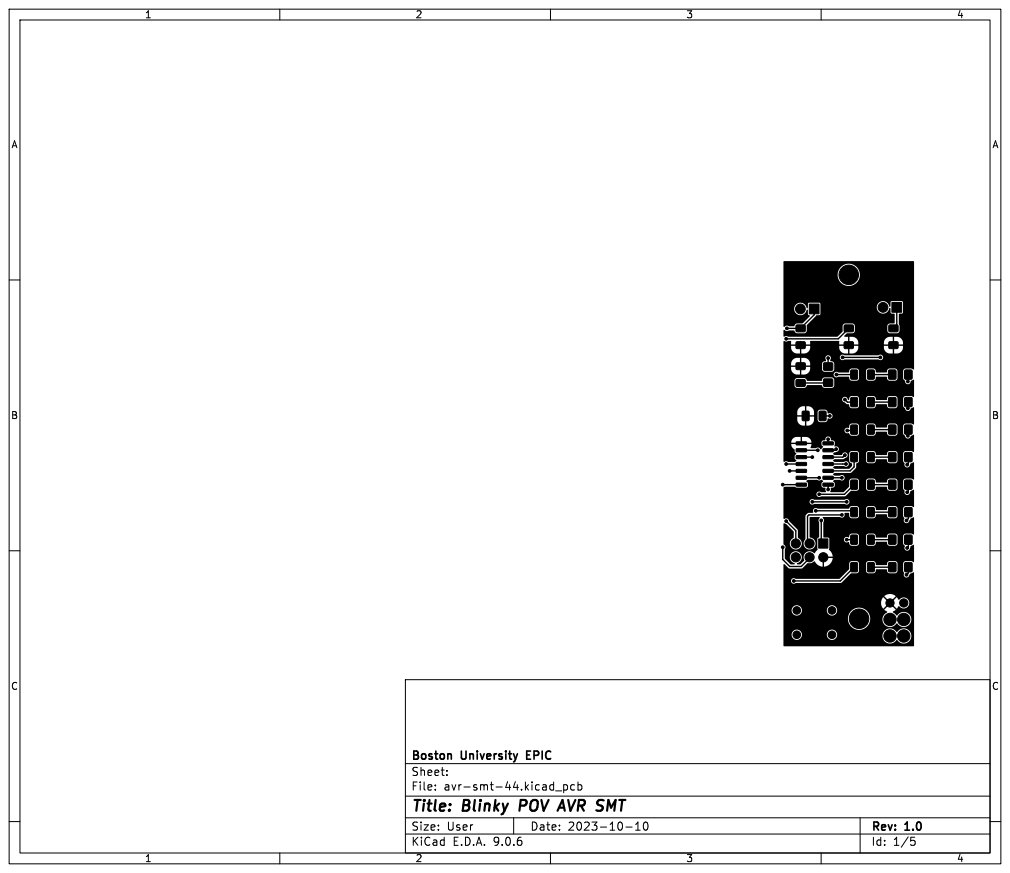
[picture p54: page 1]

Id: 1/5 Title: Blinky POV AVR SMT

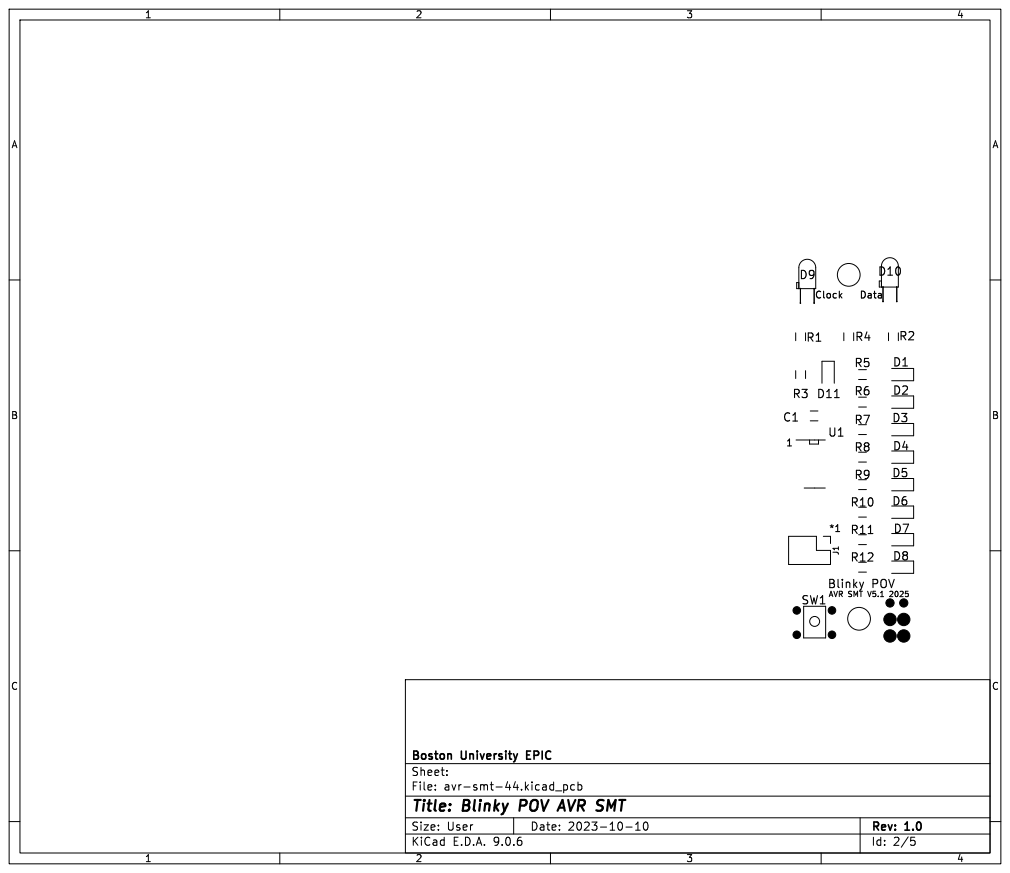
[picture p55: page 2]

Id: 2/5 Title: Blinky POV AVR SMT

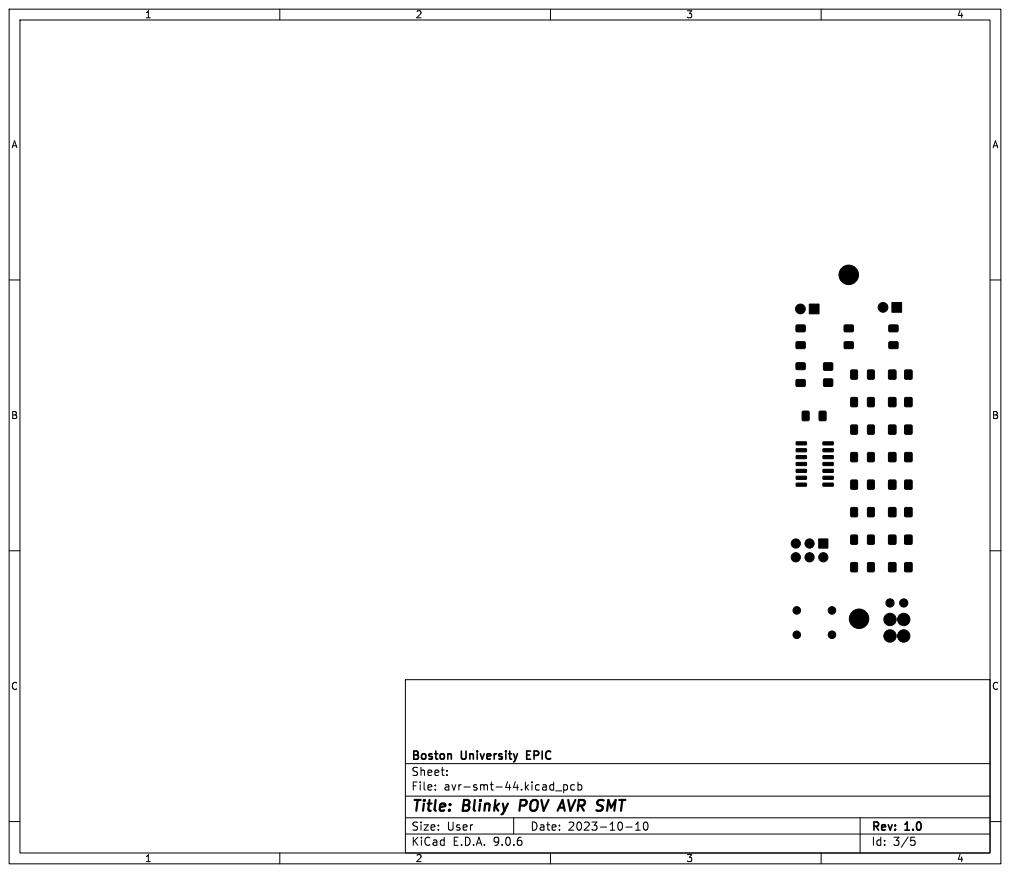
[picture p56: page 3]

Id: 3/5 Title: Blinky POV AVR SMT

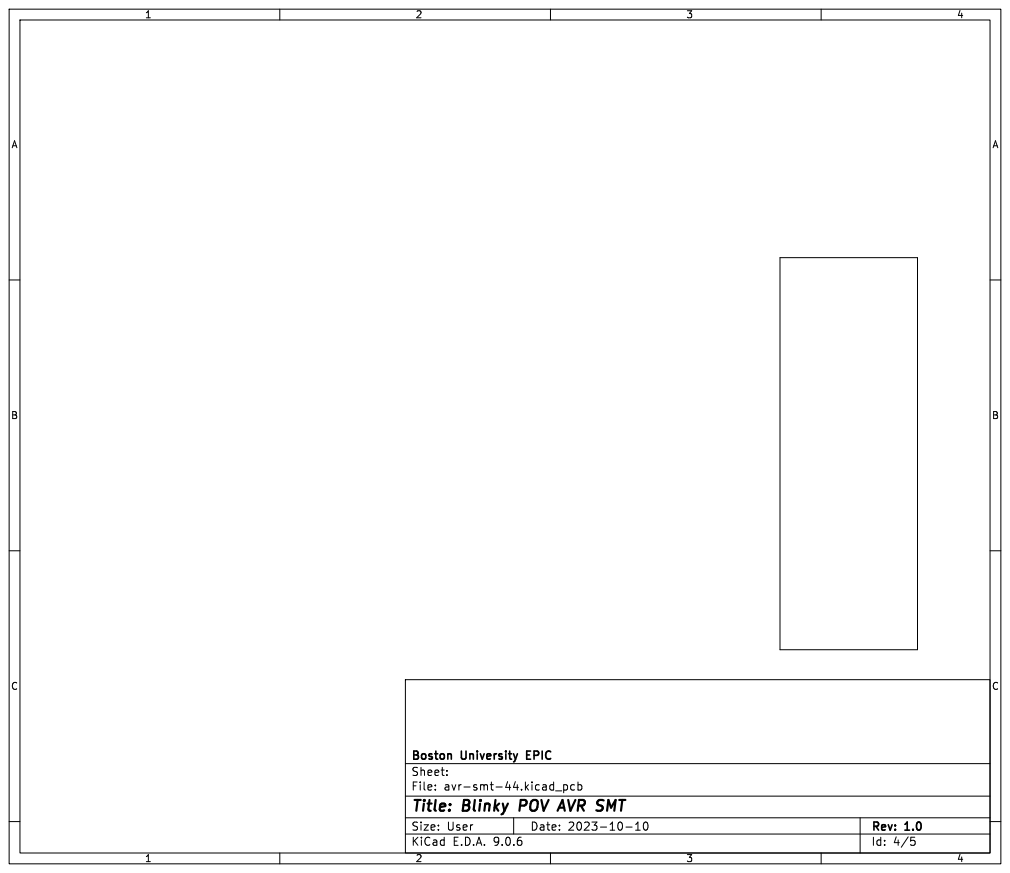
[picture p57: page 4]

Id: 4/5 Title: Blinky POV AVR SMT

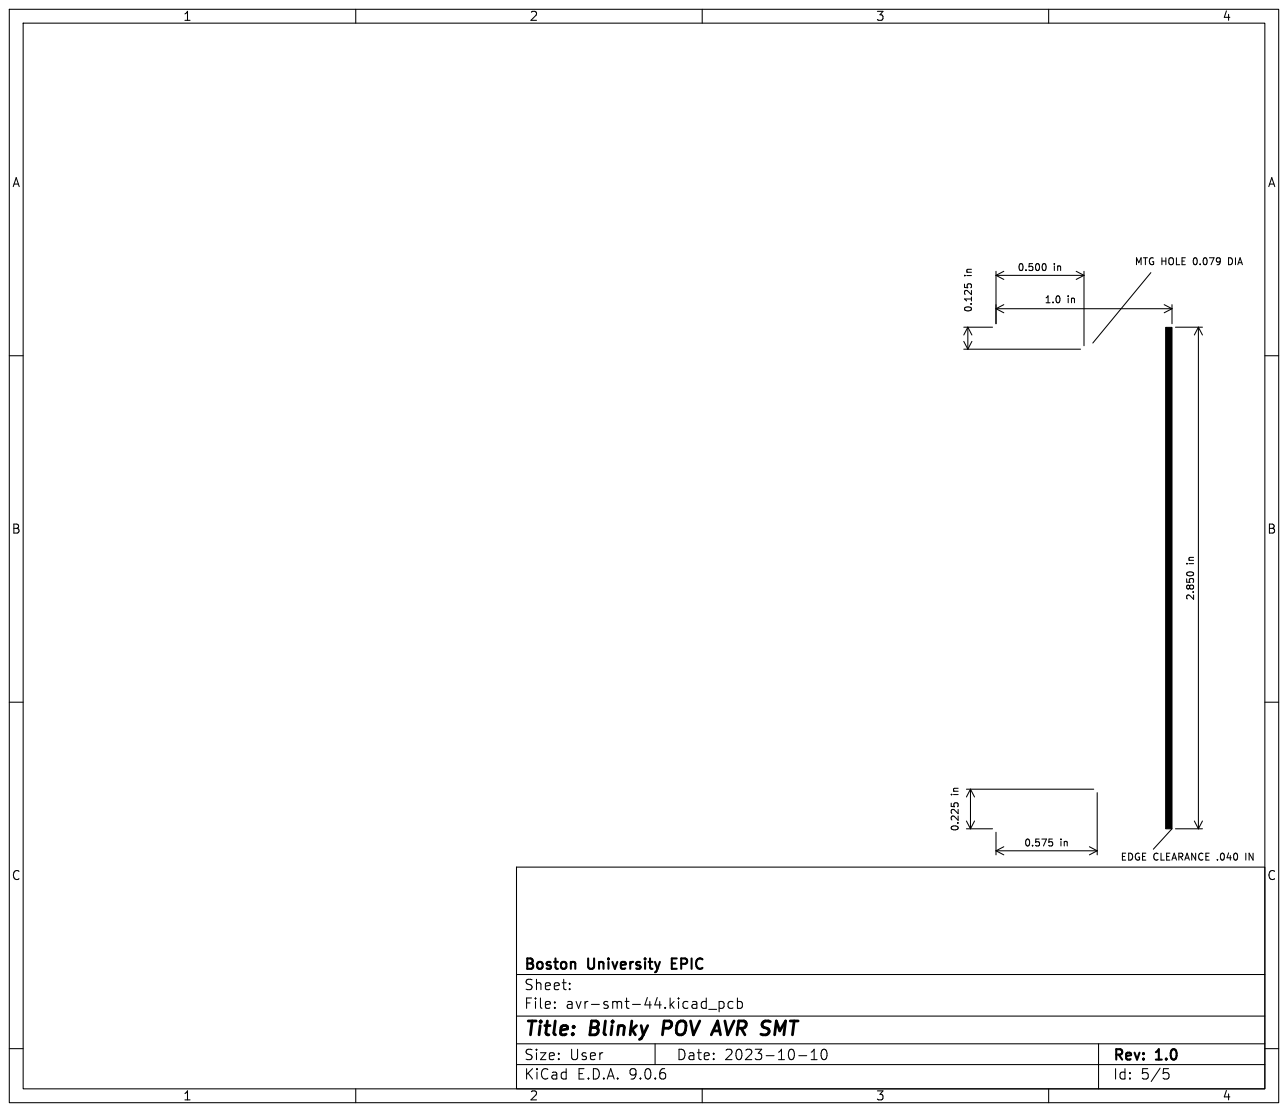
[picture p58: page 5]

Id: 5/5 Title: Blinky POV AVR SMT

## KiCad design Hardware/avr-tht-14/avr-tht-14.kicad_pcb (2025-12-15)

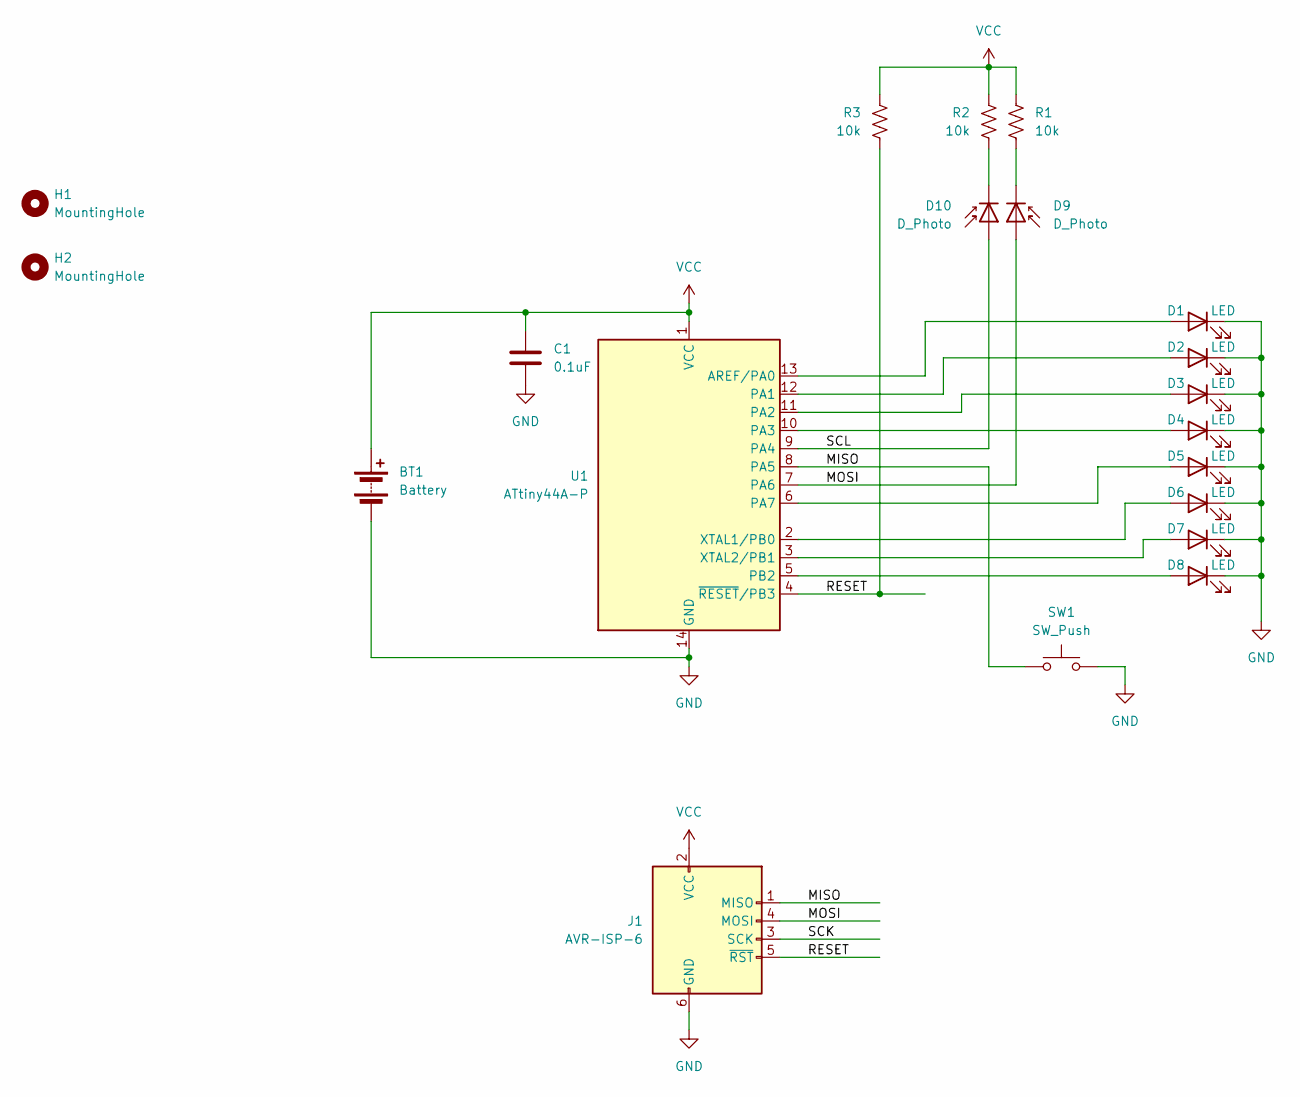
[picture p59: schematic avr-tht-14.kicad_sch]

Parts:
BT1: Battery; PinHeader_1x02_P2.54mm_Vertical
C1: 0.1uF; C_Disc_D6.0mm_W2.5mm_P5.00mm
D1, D2, D3, D4, D5, D6, D7, D8: LED; LED_D5.0mm
D9, D10: D_Photo; LED_D3.0mm
H1, H2: MountingHole; MountingHole_4.3mm_M4
J1: AVR-ISP-6; PinHeader_2x03_P2.54mm_Vertical
R1, R2, R3: 10k; R_Axial_DIN0207_L6.3mm_D2.5mm_P10.16mm_Horizontal
SW1: SW_Push; BTN-B3F-1000
U1: ATtiny44A-P; DIP-14_W7.62mm

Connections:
/MISO: J1.1 (MISO), SW1.1, U1.8 (PA5)
/MOSI: D9.2 (A), J1.4 (MOSI), U1.7 (PA6)
/RESET: J1.5 (~RST), R3.2, U1.4 (~RESET/PB3)
/SCK: J1.3 (SCK)
/SCL: D10.2 (A), U1.9 (PA4)
GND: BT1.2 (-), C1.2, D1.1 (K), D2.1 (K), D3.1 (K), D4.1 (K), D5.1 (K), D6.1 (K), D7.1 (K), D8.1 (K), J1.6 (GND), SW1.2, U1.14 (GND)
unnamed: D1.2 (A), U1.13 (AREF/PA0)
unnamed: D2.2 (A), U1.12 (PA1)
unnamed: D3.2 (A), U1.11 (PA2)
unnamed: D4.2 (A), U1.10 (PA3)
unnamed: D5.2 (A), U1.6 (PA7)
unnamed: D6.2 (A), U1.2 (XTAL1/PB0)
unnamed: D7.2 (A), U1.3 (XTAL2/PB1)
unnamed: D8.2 (A), U1.5 (PB2)
unnamed: D9.1 (K), R1.2
unnamed: D10.1 (K), R2.2
VCC: BT1.1 (+), C1.1, J1.2 (VCC), R1.1, R2.1, R3.1, U1.1 (VCC)

Board: 2 copper layers, 20 parts (0 on the bottom side), 16 nets, no tracks yet.

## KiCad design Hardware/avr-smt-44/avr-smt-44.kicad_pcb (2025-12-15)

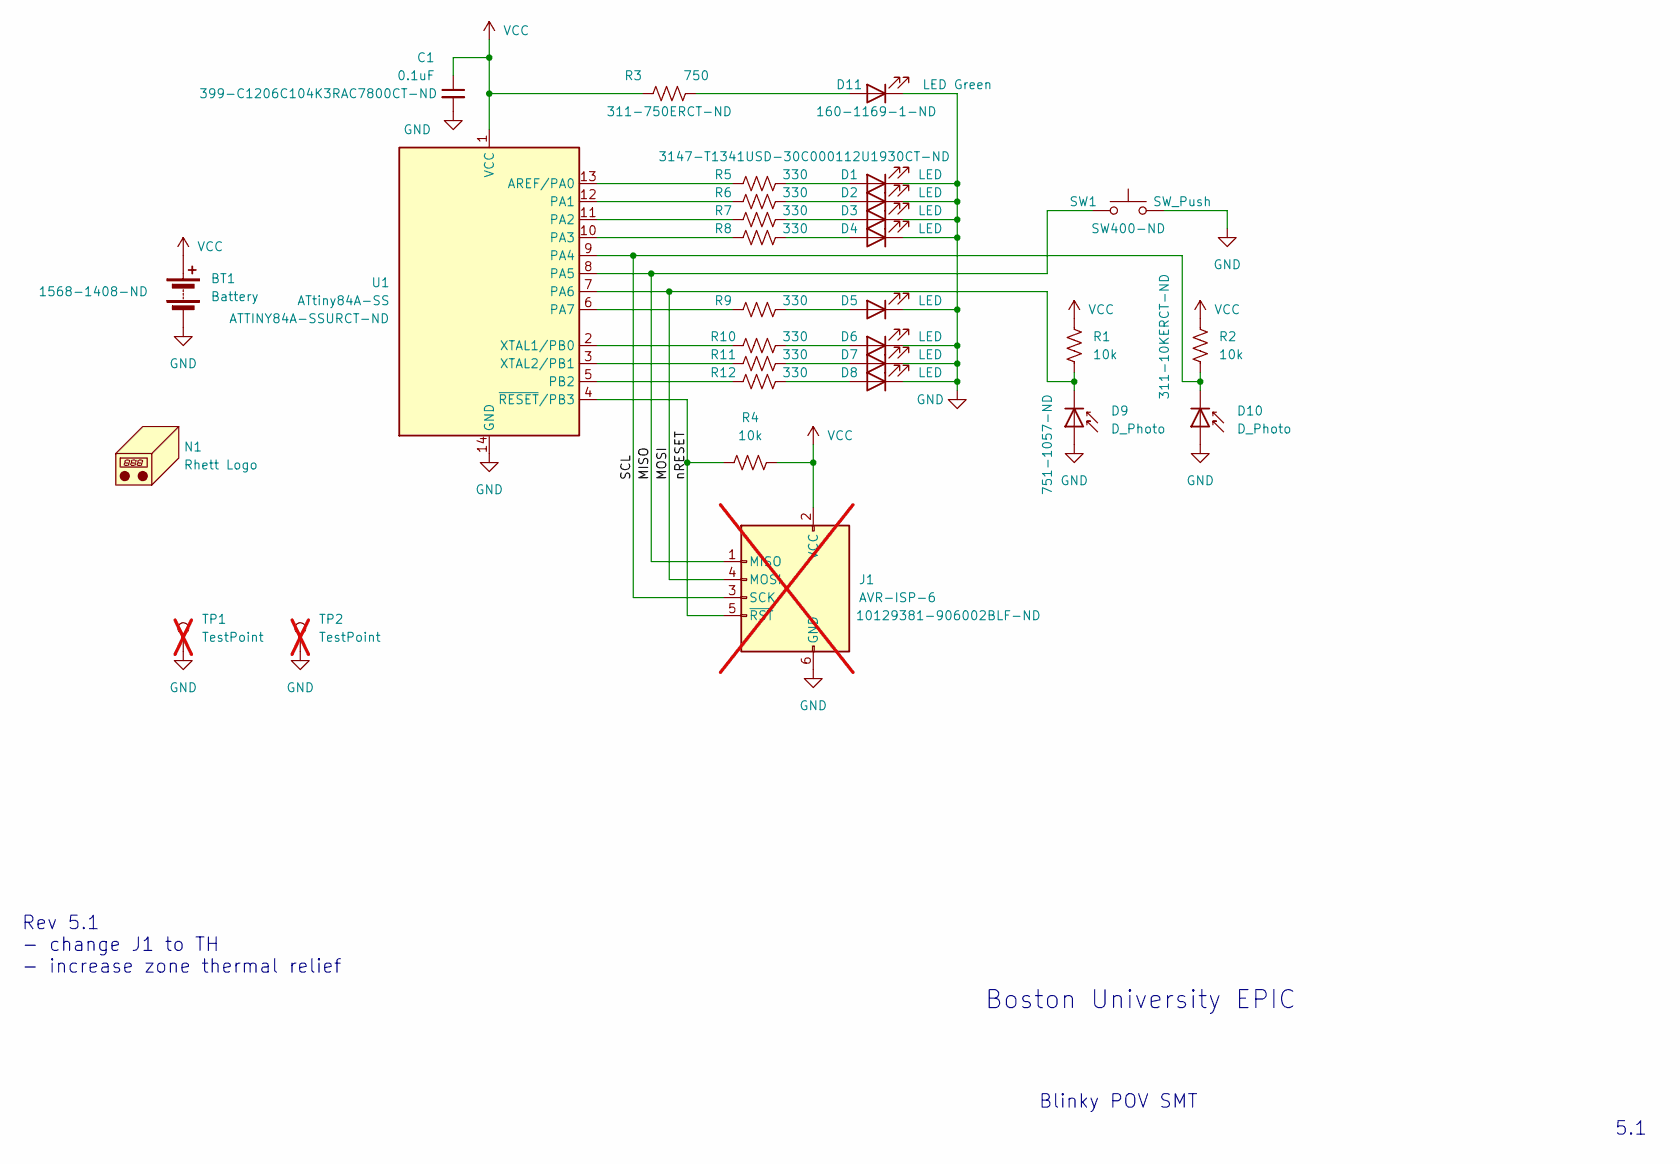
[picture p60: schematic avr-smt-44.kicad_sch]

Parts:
BT1: Battery; 2PIN_battery_new2
C1: 0.1uF; C_1206_3216Metric_Pad1.33x1.80mm_HandSolder
D1, D2, D3, D4, D5, D6, D7, D8: LED; LED_1206_3216Metric_Pad1.42x1.75mm_HandSolder
D9, D10: D_Photo; LED_D3.0mm_Horizontal_O3.81mm_Z2.0mm
D11: LED Green; LED_1206_3216Metric_Pad1.42x1.75mm_HandSolder
J1: AVR-ISP-6; PinHeader_2x03_P2.54mm_Vertical; not fitted
N1: Rhett Logo; rhett_logo
R1, R2, R4: 10k; R_1206_3216Metric_Pad1.30x1.75mm_HandSolder
R3: 750; R_1206_3216Metric_Pad1.30x1.75mm_HandSolder
R5, R6, R7, R8, R9, R10, R11, R12: 330; R_1206_3216Metric_Pad1.30x1.75mm_HandSolder
SW1: SW_Push; BTN-B3F-1000
TP1, TP2: TestPoint; TestPoint_Loop_D3.80mm_Drill2.0mm; not fitted
U1: ATtiny84A-SS; SOIC-14_3.9x8.7mm_P1.27mm

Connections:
/MISO: J1.1 (MISO), SW1.1, U1.8 (PA5)
/MOSI: D9.1 (K), J1.4 (MOSI), R1.2, U1.7 (PA6)
/SCL: D10.1 (K), J1.3 (SCK), R2.2, U1.9 (PA4)
/nRESET: J1.5 (~RST), R4.1, U1.4 (~RESET/PB3)
GND: BT1.2 (-), C1.2, D1.1 (K), D2.1 (K), D3.1 (K), D4.1 (K), D5.1 (K), D6.1 (K), D7.1 (K), D8.1 (K), D9.2 (A), D10.2 (A), D11.1 (K), J1.6 (GND), SW1.2, TP1.1, TP2.1, U1.14 (GND)
unnamed: D1.2 (A), R5.2
unnamed: D2.2 (A), R6.2
unnamed: D3.2 (A), R7.2
unnamed: D4.2 (A), R8.2
unnamed: D5.2 (A), R9.2
unnamed: D6.2 (A), R10.2
unnamed: D7.2 (A), R11.2
unnamed: D8.2 (A), R12.2
unnamed: D11.2 (A), R3.2
unnamed: R5.1, U1.13 (AREF/PA0)
unnamed: R6.1, U1.12 (PA1)
unnamed: R7.1, U1.11 (PA2)
unnamed: R8.1, U1.10 (PA3)
unnamed: R9.1, U1.6 (PA7)
unnamed: R12.1, U1.5 (PB2)
unnamed: R10.1, U1.2 (XTAL1/PB0)
unnamed: R11.1, U1.3 (XTAL2/PB1)
VCC: BT1.1 (+), C1.1, J1.2 (VCC), R1.1, R2.1, R3.1, R4.2, U1.1 (VCC)

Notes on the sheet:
Rev 5.1 - change J1 to TH - increase zone thermal relief
5.1
Boston University EPIC
Blinky POV SMT

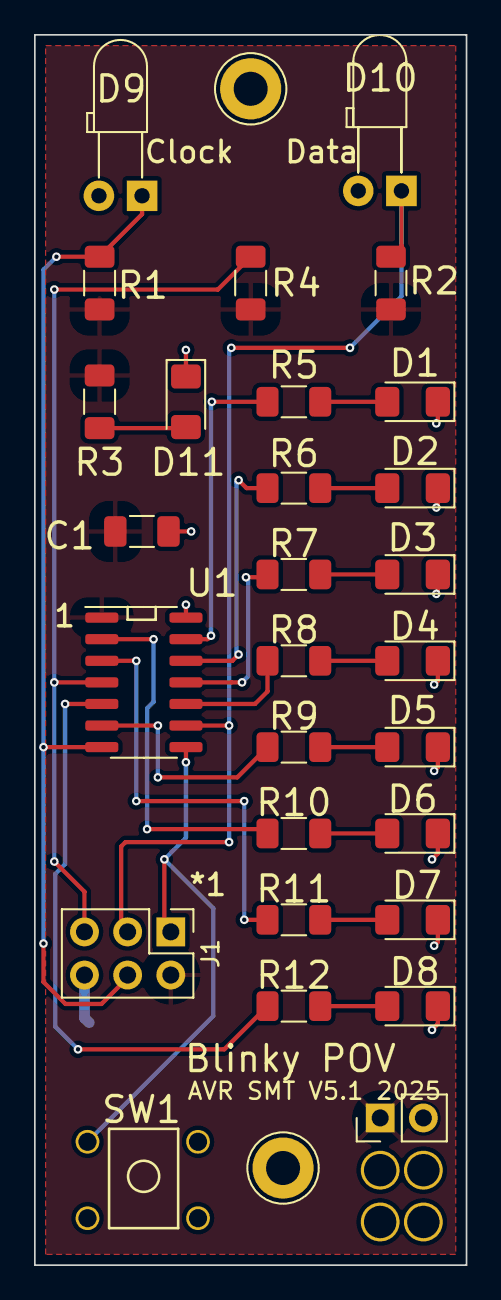
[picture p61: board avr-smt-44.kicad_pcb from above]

Board: 2 copper layers, 25.4 x 72.4 mm, 31 parts (1 on the bottom side), 23 nets.

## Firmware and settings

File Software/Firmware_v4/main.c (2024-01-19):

/*
 * main.c - BlinkyPov/AVR downloader
 *
 * Mods:
 * 2012-11-25, esh -- initial working version.  Supports download of one font-based
 * message to EEPROM.  Displays message on power-up, waits for button press.
 * 2012-11-26, esh -- port for Rev2 board
 *
 * TODO:
 * Implement pixel-based messages, multiple messages
 *
 * EEPROM memory format
 *   each character is 5 bytes wide
 *
 * byte 0     - data size
 * byte 1 [0] -
 * byte 2 [1] - bits 2-5 speed code
 * byte 3 [2] - message length
 * byte 4 [3] - start of message.  5 bytes per character
 *
 * LED "blink code" is a binary patter which flashes 5 times fast
 *
 * Power-up LED sequence (button not pressed)
 *   All OFF
 *   All ON
 *   power-up in a chase from top to bottom
 *   blink code 1
 *   display EEPROM data size (3 + message size) on low 4 LEDS (D8 always on)
 *   display message indefinitely
 *
 * Power-up (button pressed)
 *   blink code 7
 *   reset EEPROM to default "EPIC!" message
 *   display message indefinitely
 *
 * Programming (button pressed in display mode)
 *   Set bottom LED only on
 *   Take background light reading, wait for button release
 *   Delay 1s
 *   Expect hex data
 *   blink code 15 once for data
 *   blink code 15 again for EOF
 *   display message indefinitely
 */

#define USE_EEPROM

#define USE_UART

#include <avr/io.h>
#include <util/delay.h>
#include <avr/eeprom.h>
#include <string.h>

#include "font_table.h"
#define FONT_WIDTH 5	/* bytes per character in font */

#define LED_PORTA 0
#define LED_PORTB 1

// default message "EPIC!"
static uint8_t default_msg[] = { 0x08, 0x01, 0x1c, 0x05, 0x0e, 0x19, 0x12, 0x0c, 0x25 };

// LED pin assignments
const uint8_t led_port_code[] PROGMEM = {
  // these are valid for Rev4 layout for 2014 (and 2023 SMT version)
  LED_PORTA, 0,
  LED_PORTA, 1,
  LED_PORTA, 2,
  LED_PORTA, 3,
  LED_PORTA, 7,
  LED_PORTB, 0,
  LED_PORTB, 1,
  LED_PORTB, 2
};

#define led_bit(n) (pgm_read_byte(&(led_port_code[((n)<<1)+1])))
#define led_port(n) (pgm_read_byte(&(led_port_code[((n)<<1)])))

static void inline setup_led_ports()
{
  uint8_t i;
  for( i=0; i<8; i++) {
    if( led_port(i) == LED_PORTA)
      DDRA |= _BV(led_bit(i));
    else
      DDRB |= _BV(led_bit(i));
  }
}

// create masks for ports A/B for LEDs specified
// PORT A = low byte
// PORT B = high byte
static uint16_t led_mask( uint8_t leds)
{
  uint16_t v = 0;
  uint8_t i;
  uint8_t b = 1;

  for( i=0; i<8; i++) {
    if( leds & b) {
      if( led_port(i) == LED_PORTA)
	v |= _BV(led_bit(i));
      else
	v |= (_BV(led_bit(i)) << 8);
    }
    b <<= 1;
  }
  return v;
}

// toggle LEDs per mask
static void led_flip( uint8_t flip_mask)
{
  uint16_t v = led_mask( flip_mask);
  PORTA ^= (v & 0xff);
  PORTB ^= ((v>>8) & 0xff);
}

// turn on LEDs per mask
static void led_on( uint8_t on_mask)
{
  uint16_t v = led_mask( on_mask);
  PORTA |= (v & 0xff);
  PORTB |= ((v>>8) & 0xff);
}

// turn off LEDs per mask
static void led_off( uint8_t off_mask)
{
  uint16_t v = led_mask( off_mask);
  PORTA &= ~(v & 0xff);
  PORTB &= ~((v>>8) & 0xff);
}

// set LEDs per mask
static void led_set( uint8_t set_mask)
{
  led_off( 0xff);
  led_on( set_mask);
}

//
// blink binary value 'e' on LEDs 5 times fast
//
void error_blink( uint8_t e) {
  int i;
  for( i=0; i<5; i++) {
    led_set( e);
    _delay_ms(100);
    led_set( 0);
    _delay_ms(100);
  }
}



#ifdef USE_UART
#define UART_PORT PORTA
#define UART_DDR DDRA
#define UART_TX_BIT _BV(5)
#endif

#define SW_PORT PORTA
#define SW_PIN PINA
#define SW_BIT 5
#define SW_MASK _BV(SW_BIT)

// ok for Rev4 layout
#define ADC_DATA 4
#define ADC_CLK 6

#define CLK_VAL 1
#define DATA_VAL 2

// buffer for intel hex records (size 16)
#define BUFSIZ 24
static uint8_t ihex[BUFSIZ];

// buffer for EEPROM image
#define EEBUFSIZ 128
static uint8_t eebuf[EEBUFSIZ];

static uint8_t eep_nd;

// offsets of things in the hex record
#define IHEX_LEN 0
#define IHEX_ADDR 1
#define IHEX_TYPE 3
#define IHEX_DATA 4

// number of bytes in latest hex record
static uint8_t ihex_nd;

// address of latest hex record
static uint16_t ihex_addr;

// number of ADC samples to average
#define NAV 30

// logic threshold in ADC units (30 ~ 100mV)
#define THR 30

// variables for blinky receiver
static int16_t base_d, base_c;
static int32_t sum_d, sum_c;

// loop variable
static uint16_t k;
static int16_t a;


// flag:  button pressed, do reset
static uint8_t do_reset;

// global mode
static uint8_t mode;

#define MODE_BLINKY 0
#define MODE_LOAD 1



#ifdef USE_UART
// send a character to UART at 9600 baud using software delay
#define BAUD_DELAY_FUDGE 10
#define BAUD_DELAY_US ((1000000/9600)-BAUD_DELAY_FUDGE)

static void inline send_uart_bit( uint8_t b)
{
  if( b)
    UART_PORT |= UART_TX_BIT;
  else
    UART_PORT &= ~UART_TX_BIT;
  _delay_us( BAUD_DELAY_US);
}

// send byte to UART
static void uart_putc( uint8_t c)
{
  send_uart_bit( 0);		/* start bit */
  send_uart_bit( c & 1);
  send_uart_bit( c & 2);
  send_uart_bit( c & 4);
  send_uart_bit( c & 8);
  send_uart_bit( c & 0x10);
  send_uart_bit( c & 0x20);
  send_uart_bit( c & 0x40);
  send_uart_bit( c & 0x80);
  send_uart_bit( 1);		/* stop bit */
}

// convert nibble to hex
#define nibble_to_hex(n) ((n)>9?((n)+('A'-10)):((n)+'0'))

// send hex byte to UART
static void uart_hex2( uint8_t c)
{
  uart_putc( nibble_to_hex( (c>>4)&0xf));
  uart_putc( nibble_to_hex( c & 0xf));
}

// send hex word to UART
static void uart_hex4( uint16_t w) {
  uart_hex2( w>>8);
  uart_hex2( w);
}

// send newline sequence
static void inline crlf()
{
  uart_putc( 0x0d);
  uart_putc( 0x0a);
}
#endif

/*
 * Do all the startup-time peripheral initializations.
 */
static void ioinit(void)
{
  setup_led_ports();
#ifdef USE_UART
  UART_DDR |= UART_TX_BIT;
#endif
  SW_PORT |= SW_MASK;		/* pull-up on switch */
  ADCSRA |= _BV(ADEN);		/* enable ADC, default settings */
  //  ADCSRB |= _BV(ADLAR);		/* left adjust result */
  ADMUX = 7;
}



uint16_t read_adc( uint8_t ch)
{
  uint8_t lo, hi;

  ADMUX = ch;
  ADCSRA |= _BV(ADSC);
  loop_until_bit_is_clear( ADCSRA, ADSC);
  lo = ADCL;
  hi = ADCH;
  
  return( (hi<<8) | lo);
}


// sample the light sensor once (with averaging)
// return bit 0 = clk state  bit 1 = data state
uint8_t sample_clk_data() {
  uint8_t rv;

  sum_d = sum_c = 0;
  for( k=0; k<NAV; k++) {
    a = read_adc( ADC_DATA);
    sum_d += a;
    a = read_adc( ADC_CLK);
    sum_c += a;
  }

  rv = 0;
  if( (base_d - (sum_d / NAV)) >= THR)
    rv |= DATA_VAL;
  if( (base_c - (sum_c / NAV)) >= THR)
    rv |= CLK_VAL;

  return rv;
}

//
// wait for clock state change or button press
// return data state, set do_reset on button press
//
uint8_t wait_for_clock( uint8_t c)
{
  uint8_t s;

  do {
    s = sample_clk_data();
    if( bit_is_clear( SW_PIN, SW_BIT)) {
      do_reset = 1;
      return 0;
    }
  } while( (s & CLK_VAL) != c);

  return( (s & DATA_VAL) != 0);
}

// receive blinky byte
uint8_t rx_byte() {

  uint8_t bit, byte, d;
  uint8_t i;

  bit = 0x80;
  byte = 0;

  for( i=0; i<4; i++) {
    d = wait_for_clock( 1);
    if( do_reset) return 0;
    if( d)
      byte |= bit;
    bit >>= 1;
    d = wait_for_clock( 0);
    if( do_reset) return 0;
    if( d)
      byte |= bit;
    bit >>= 1;
  }
  
  //  led_flip( 0x80);		/* toggle LED8 */
  led_set( byte);
  
  return byte;
}

// receive an intel hex record into buffer
// return type or -1 on failure
int rx_ihex() {

  uint8_t* p = ihex;
  uint8_t i, n, c, s;

  n  = rx_byte();	/* get length */
  if( n == 0)		/* ignore length 0 records for now */
    return 0;

  ihex_nd = n;
  *p++ = n;

  for( i=0; i<3; i++) {
    *p++ = rx_byte();	/* get addr_hi, addr_lo, type */
    if( do_reset) return -2;
  }
  ihex_nd = ihex[IHEX_LEN];

  ihex_addr = (ihex[IHEX_ADDR] << 8) | ihex[IHEX_ADDR+1];
  if( ihex_nd > 0 && ihex_nd <= 0x10) {
    for( i=0; i<ihex_nd; i++) {
      *p++ = rx_byte();		/* get data */
      if( do_reset) return -2;
    }
  }
  c = rx_byte();		/* get checksum */
  *p++ = c;			/* store checksum at end */
  if( do_reset) return -2;
  // calculate sum of received bytes
  s = 0;
  for( i=0; i<(ihex_nd+4); i++)
    s += ihex[i];

  s = (s ^ 0xff)+1;
  *p++ = s;			/* store raw sum */

  if( c == s ) {
    return ihex[IHEX_TYPE];
  } else {
    return -1;
  }
}



// delay one column with code 0..15
// about 0.5 ms per unit
void delay_column( uint8_t d)
{
  if( d < 15)
    _delay_loop_2( d * 128);
  else
    _delay_ms( 500);
}

// read EEPROM message to eep_nd, eebuf
//   return:   0 - no/invalid message
//            >0 - length of mesage
int read_eeprom() {
  int i;
  eep_nd = eeprom_read_byte( (void *)0);

  if( eep_nd < 4 || eep_nd > EEBUFSIZ)
    return 0;
  
  eeprom_read_block( eebuf, (void *)1, eep_nd);

  return eep_nd;
}

// display messages if any in EEPROM
// returns:
// 0 - no messages to display
// 1 - button pressed
//
int show_messages() {
  uint8_t i, t, n, j, speed, c;

  n = read_eeprom();
  if( !n) return 0;

  // display EEPROM buffer size on low LEDs, high one on
  led_set( (n&0x7f) | 0x80);
  _delay_ms( 500);
  // turn off all LEDs
  led_off( 0xff);
  _delay_ms( 500);

  n = eebuf[2];		/* length of first message */
  speed = (eebuf[1] >> 2) & 15; /* speed code 0-15, 7=default */

  // loop until button is pressed
  while( bit_is_set( SW_PIN, SW_BIT) ) {

    // space between messages
    for( j=0; j<10; j++)
      delay_column( speed);

    // loop over message
    for( i=0; i<n; i++) {

// #ifdef USE_UART
//       uart_putc( 'd');
//       uart_hex2( i);
//       uart_putc( '=');
// #endif
      // look up character
      t = eebuf[3+i] * FONT_WIDTH;
      if( t < sizeof(font_table)) {
	for( j=0; j<FONT_WIDTH; j++) {
	  c = pgm_read_byte(&(font_table[t+j]));
	  led_set( c);
// #ifdef USE_UART
// 	  uart_hex2( c);
// 	  uart_putc( ' ');
// #endif
	  delay_column( speed);
	}
      } else {		// invalid code probably a space
	// delay for three extra columns for space
//#ifdef USE_UART
//	uart_putc('S');
//#endif
	delay_column( speed);
	delay_column( speed);
	delay_column( speed);
      }
      led_off( 0xff);
      delay_column( speed); /* two blank columns between characters */
      delay_column( speed);
// #ifdef USE_UART
//       crlf();
// #endif
    }
  }

  // fall out if button pressed
  return 1;
}


void dump_eeprom( uint8_t n) {
#ifdef USE_UART
  int i;
  // read and print the first 16 bytes of the EEPROM
  // use the eebuf temporarily
  eeprom_read_block( eebuf, (void *)0, EEBUFSIZ);

  uart_putc('E');
  crlf();
  for( i=0; i<16; i++) {
    uart_hex2( eebuf[i]);
    uart_putc( ' ');
  }
  uart_putc( '*');
  crlf();
#endif
}


int main(void)
{
  uint8_t i, j, n, c;
  uint8_t speed;
  uint8_t t;
  uint8_t nblk;

  ioinit();

  dump_eeprom( 16);

  // check for button held down at power-up, and reset to default message
  if( bit_is_clear( SW_PIN, SW_BIT)) {
    // do reset stuff
    error_blink(7);
    eeprom_update_block( default_msg, (void *)0, sizeof(default_msg)); /* then the data */

    // wait for button release plus some delay
    loop_until_bit_is_set( SW_PIN, SW_BIT);
    _delay_ms( 100);
    dump_eeprom( 16);
  }

  // test LEDs
  led_off( 0xff);
  _delay_ms( 100);
  led_on( 0xff);
  _delay_ms( 100);
  led_off( 0xff);  
  for( i=0; i<8; i++) {
    _delay_ms(100);
    led_on( 1<<i);
  }
  _delay_ms(100);
  led_off( 0xff);


  // Power-up:   check for EEPROM message and display it indefinitely until
  // the button is pressed
  error_blink(1);

  i = show_messages();

  error_blink(2);

  do_reset = 1;

  while( 1) {

    // see if button is pressed
    // if so, recalibrate threshold, reset bit counter
    if( bit_is_clear( SW_PIN, SW_BIT) || do_reset) {

#ifdef USE_UART
      uart_putc( 'R');
      crlf();
#endif
      led_set( 0x80);

      // measure background level
      sum_d = sum_c = 0;
      for( k=0; k<NAV; k++) {
	a = read_adc( ADC_DATA);
	sum_d += a;
	a = read_adc( ADC_CLK);
	sum_c += a;
	_delay_ms(1);
      }
      base_d = sum_d / NAV;
      base_c = sum_c / NAV;

      // now wait for button to be released, wait a while

      // loop while button is still pressed
      while( bit_is_clear( SW_PIN, SW_BIT))
	;

      _delay_ms( 1000);
      // turn off all LEDs
      led_off( 0xff);

      do_reset = 0;
      ihex_nd = 0;
      memset( eebuf, 0xab, EEBUFSIZ);
    } // if( button pressed)...

    // look for intel hex records
    eep_nd = 0;

    while( !do_reset) {

      t = rx_ihex();
      ++nblk;
      
      if( do_reset)
	break;

      error_blink(15);

      if( t == 0) {		/* end-of-file record */
#ifdef USE_EEPROM
	if( eep_nd) {
	  // copy EEPROM RAM buffer to EEPROM
	  eeprom_write_byte( (void *)0, eep_nd); /* first byte is size */
	  eeprom_write_block( eebuf, (void *)1, eep_nd); /* then the data */
	}
#endif	
	break;
      }

      if( t == 6) {		/* EEPROM message */
	i = ihex_addr + ihex[IHEX_LEN]; /* top address */
	// copy data to EEPROM buffer in RAM

	if( ihex_addr < 128 && i < EEBUFSIZ) {
	  memcpy( &eebuf[ihex_addr], &ihex[IHEX_DATA], ihex[IHEX_LEN]);
	  if( i > eep_nd)
	    eep_nd = i;
	}
      }

    }

    // display messages if any, wait for button press
    show_messages();

  }

}

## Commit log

2023-09-16 SMT 44 version, placement done
    [avr-smt-44.kicad_pcb, avr-smt-44.kicad_sch]
2023-09-16 Add series R, re-place
    [avr-smt-44.kicad_pcb, avr-smt-44.kicad_sch]
2023-09-16 V5 for submit
    [avr-smt-44-B_Cu.gbr, avr-smt-44-B_Mask.gbr, avr-smt-44-B_Silkscreen.gbr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]
2023-10-10 assembly docs
    [avr-smt-44-assembly-list.ods, avr-smt-44.kicad_pcb, avr-smt-44.kicad_sch]
2023-10-21 add pdf schematic
2023-11-11 V5.1 PCB, notes
    [avr-smt-44.kicad_pcb, avr-smt-44.kicad_sch]
2023-11-13 Add power-up reset of EEPROM on button press
    [main.c]
2023-11-16 V5.1 as built
    [avr-smt-44-B_Cu.gbr, avr-smt-44-B_Mask.gbr, avr-smt-44-B_Silkscreen.gbr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]
2024-01-19 fix up 3D model, update instructions
    [B3F-1000.step, avr-smt-44.kicad_pcb]
2024-02-08 updated instructions and assy dwg for 2/12 class
    [avr-smt-44-assembly-list.ods, avr-smt-44.kicad_pcb, avr-smt-44.kicad_sch]
2024-11-13 add some docs
    [avr-smt-44.kicad_pcb, avr-smt-44.step]
2024-11-13 Tweak documentation
    [avr-smt-44.kicad_sch]
2025-05-15 re-spin 2025
    [avr-smt-44-B_Cu.gbr, avr-smt-44-B_Mask.gbr, avr-smt-44-B_Silkscreen.gbr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]
2025-05-19 v5.1 2025 edition
    [avr-smt-44-B_Cu.gbr, avr-smt-44-B_Mask.gbr, avr-smt-44-B_Silkscreen.gbr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]
2025-12-15 New THT version
    [avr-smt-44.kicad_pcb, avr-tht-14.kicad_pcb, avr-tht-14.kicad_sch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]
